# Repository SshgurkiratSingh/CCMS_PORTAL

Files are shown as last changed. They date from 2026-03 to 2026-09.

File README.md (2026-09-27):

# CCMS Portal — Centralized Command & Monitoring System

A full-stack smart streetlight fleet management system with real-time monitoring, remote control, and analytics. This monorepo contains the Next.js operator console, AWS Lambda backend, ESP32 firmware for the edge devices, and PCB designs.

## Screenshots & Assets

| Fleet Info | Node Info | Command Menu |
|:---:|:---:|:---:|
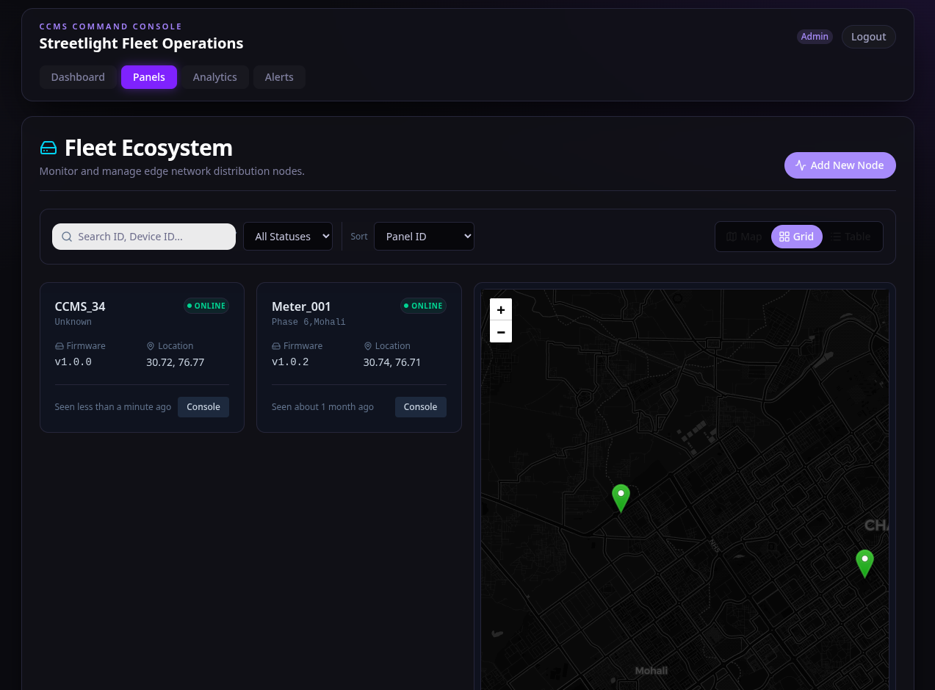
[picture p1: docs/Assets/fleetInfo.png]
Fleet
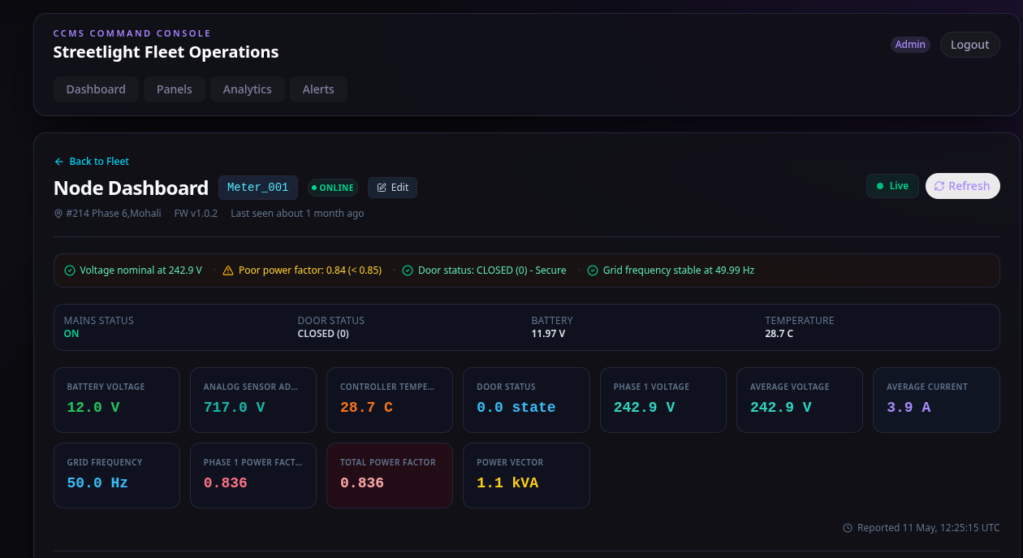
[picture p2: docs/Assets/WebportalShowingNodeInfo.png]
Node
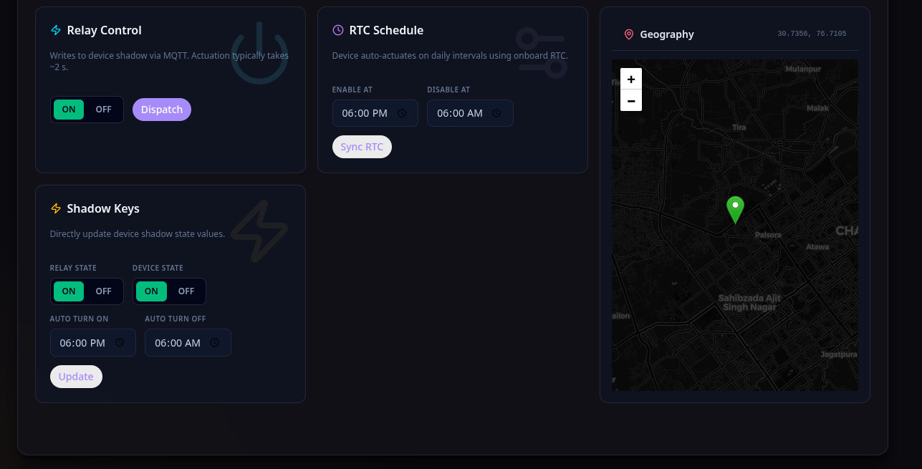
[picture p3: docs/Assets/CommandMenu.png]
Command
|  |  |  |

| Prototype | Power Supply Unit | Offsite Interface Card |
|:---:|:---:|:---:|
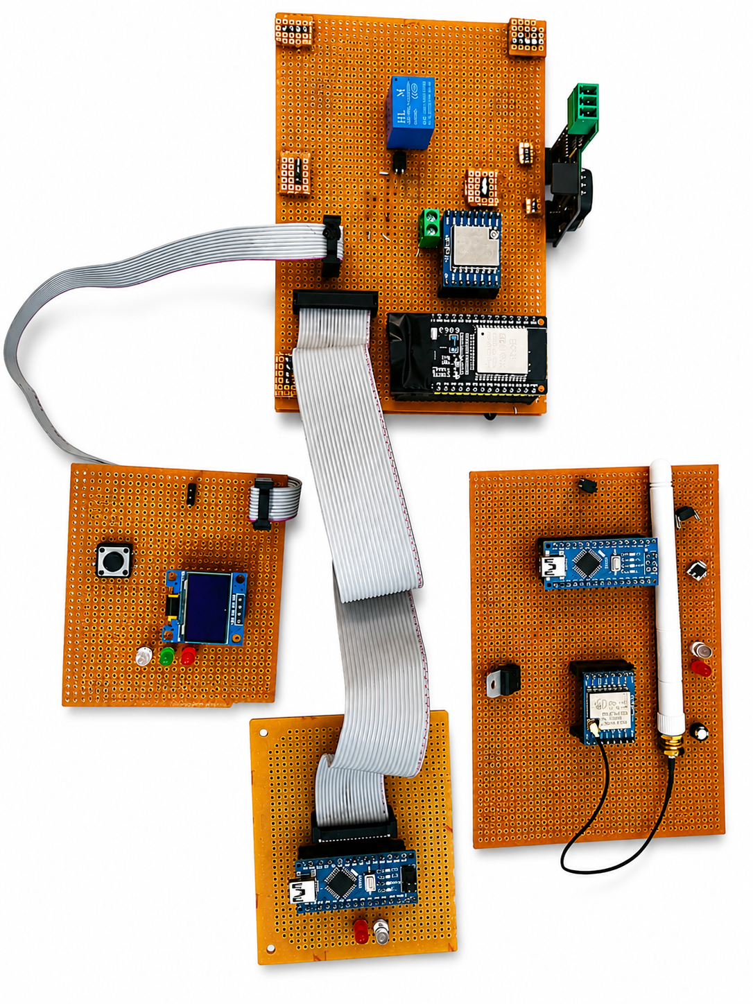
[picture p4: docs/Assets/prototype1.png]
Prototype
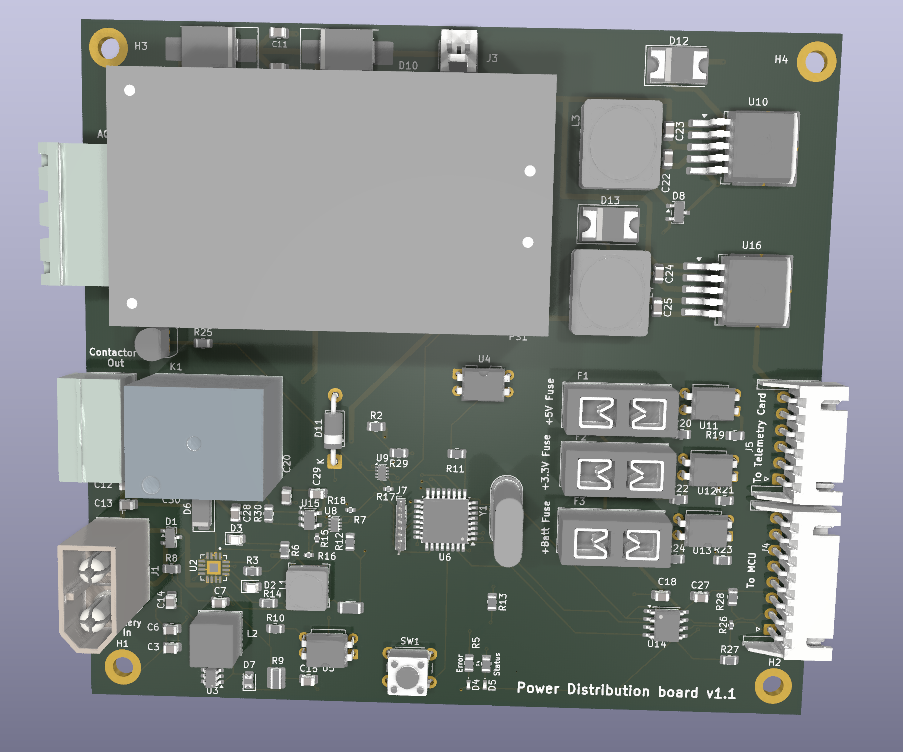
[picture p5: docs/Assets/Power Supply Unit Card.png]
PSU
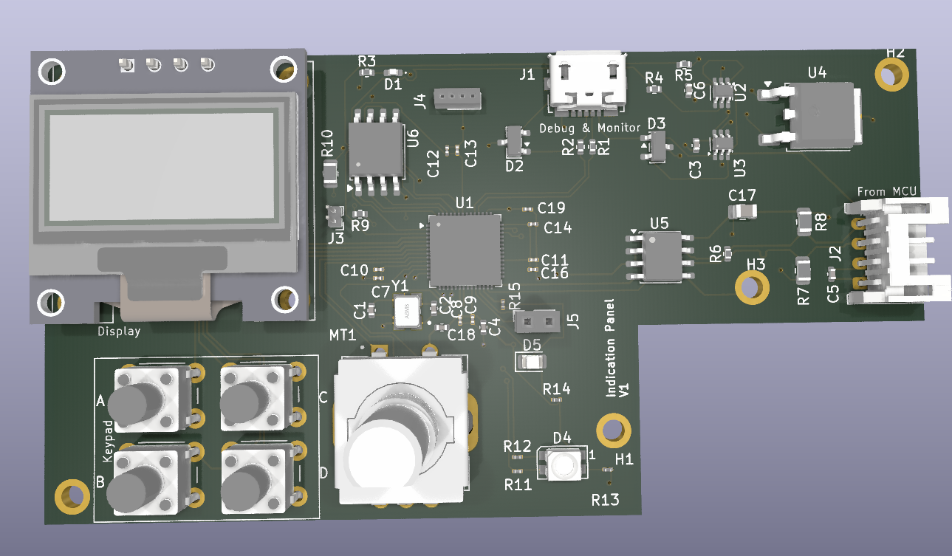
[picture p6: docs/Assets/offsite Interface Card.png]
OIC
|  |  |  |

---

## Architecture Overview

```text
┌──────────────────┐       ┌──────────────┐       ┌─────────────────┐
│ RPi Gateway + STM│──────▶│   AWS IoT    │──────▶│  SQS → Lambda   │──────▶ DynamoDB
│  (streetlights)  │  MQTT │   Core       │       │ (saveDataFromSQ)│
└──────────────────┘       └──────────────┘       └─────────────────┘
                                                          │
                                                          ▼
┌──────────────────┐       ┌──────────────┐       ┌─────────────────┐
│   Next.js App    │◀──────│   Lambda     │◀──────│  DynamoDB       │
│  (operator       │  REST │   API        │       │                 │
│   console)       │       │   Gateway    │       │                 │
└──────────────────┘       └──────────────┘       └─────────────────┘
```

### Components

| Layer | Technology | Location |
| --- | --- | --- |
| **Web Portal** | Next.js 16, React 19, Tailwind CSS v4 | [`Frontend/ccms/`](./Frontend/ccms) |
| **Backend API** | Python AWS Lambda | [`Backend/Lambda/`](./Backend/Lambda) |
| **Firmware (RPi Gateway)** | Python 3 | [`Firmware/RPi_Gateway/`](./Firmware/RPi_Gateway) |
| **Firmware (STM32 Node)** | C++ (PlatformIO), STM32 | [`Firmware/STM32_Peripheral/`](./Firmware/STM32_Peripheral) |
| **Firmware v2.0** | C++ (PlatformIO), ESP32 | [`Firmware/ESP32_wifi_CCMS_v2.0/`](./Firmware/ESP32_wifi_CCMS_v2.0) |
| **Firmware v2.0 (Pi link)** | C++ (PlatformIO), ESP32 | [`Firmware/ESP32_wifi_CCMS_v2.0_PI_link/`](./Firmware/ESP32_wifi_CCMS_v2.0_PI_link) |
| **Firmware v1.0** | C++ (PlatformIO), ESP32 | [`Firmware/ESP32_wifi_CCMS_v1.0/`](./Firmware/ESP32_wifi_CCMS_v1.0) |
| **Hardware** | PCB Designs | [`Hardware/PCB Designs/`](./Hardware/PCB%20Designs) |
| **Documentation** | MkDocs (Material theme) | [`docs/`](./docs), [`mkdocs.yml`](./mkdocs.yml) |

---

## Frontend — Operator Console (`Frontend/ccms/`)

A Next.js static export application that provides a real-time operations dashboard for managing streetlight fleets.

### Pages

| Route | Description |
| --- | --- |
| `/` | Landing page with login / dashboard links |
| `/login` | Authenticate using Dashboard Key and Admin Key |
| `/dashboard` | Fleet-wide summary (panel count, active alarms, grid metrics, energy estimate) |
| `/panels` | Browse, filter, and search all panels (map + list views) |
| `/panel?id={panelId}` | Live status, telemetry charts, command dispatch (relay, schedule, shadow keys) |
| `/manage-panel` | Register new panels with GPS coordinates |
| `/analytics` | Historical telemetry viewer with date range filtering |
| `/alerts` | Active alerts list with severity filtering and acknowledgment |

### Key Technologies

- **Framework**: Next.js 16 (`output: "export"` — fully static, no server functions)
- **UI Library**: HeroUI v3, Lucide icons
- **Charts**: Recharts (telemetry time-series)
- **Maps**: Leaflet + React-Leaflet (panel fleet locations, location picker)
- **Styling**: Tailwind CSS v4, Framer Motion (animations)
- **Auth**: API keys stored in `localStorage`, sent as `x-dashboard-key` / `x-admin-key` headers

### Environment Variables

```env
NEXT_PUBLIC_API_BASE_URL=<Lambda API Gateway endpoint>
```

Copy `Frontend/ccms/.env.example` → `Frontend/ccms/.env.local` and fill in real values.

### Run Locally

```bash
cd Frontend/ccms
npm install
npm run dev       # development server at http://localhost:3000
npm run build     # static export to Frontend/ccms/out/
```

---

## Backend — AWS Lambda (`Backend/Lambda/`)

Python-based serverless functions deployed behind API Gateway.

### Functions

| File | Purpose |
| --- | --- |
| [`lambdaAPI.py`](./Backend/Lambda/lambdaAPI.py) | REST API handler — serves dashboard snapshot, panel status, history, and commands |
| [`saveDataFromSQStoDB,py`](./Backend/Lambda/saveDataFromSQStoDB,py) | SQS-triggered function that writes incoming telemetry to DynamoDB |

### API Endpoints (via `DashboardAPIHandler`)

| Method | Query / Body | Description |
| --- | --- | --- |
| `GET` | `?enquiry=snapshot` | Returns all panels with latest data and metadata |
| `GET` | `?enquiry=history&panel_id=X&start=T&end=T` | Historical telemetry for a panel |
| `POST`  | `{ panel_id, ... }` | Register a new panel |
| `PATCH` | `{ panel_id, desired_state/schedule/shadowKeys, ... }` | Send commands to a panel |

### Test Endpoints

A Node.js test script is available at [`Backend/Lambda/TestEndpoints/getData.js`](./Backend/Lambda/TestEndpoints/getData.js) for manual API testing.

---

## Hardware — Edge Firmware

The project supports both ESP32-centric designs and a new hybrid Raspberry Pi + STM32 architecture.

| Variant | Description |
| --- | --- |
| **RPi Gateway** | Python daemon acting as an IoT gateway, handling AWS IoT MQTT and Shadow. |
| **STM32 Peripheral** | Hard-realtime STM32 node for sensors and Modbus, reports to RPi Gateway. |
| **v1.0 (ESP32)** | Base implementation with WiFi, MQTT, and energy meter reading |
| **v2.0 (ESP32)** | Enhanced version with AWS IoT Core integration, relay control, OTA-ready |
| **v2.0 PI Link (ESP32)** | Variant designed to communicate via Raspberry Pi for additional relay logic |

### Key Hardware Interfaces (RPi + STM32)

- **Raspberry Pi**: Network handling (WiFi/Ethernet), AWS IoT Core communication.
- **Serial (UART)**: Two-way communication between Pi and STM32 (Baud 115200).
- **Relay Control**: Managed by STM32 GPIO (`PA0`).
- **Modbus**: Read by STM32 via RS485 transceiver.

Build STM32 firmware with [PlatformIO](https://platformio.org/):

```bash
cd Firmware/STM32_Peripheral
pio run -t upload
```

---

## API Types

All frontend types are defined in [`Frontend/ccms/lib/api/types.ts`](./Frontend/ccms/lib/api/types.ts). Key models:

- **PanelRecord** — panel metadata, status, GPS coordinates
- **PanelLiveStatus** — real-time telemetry snapshot (voltage, current, power factor, frequency, battery, temperature, tilt)
- **TelemetryPoint** — historical data point matching live status fields
- **PanelCommandPayload** — `SET_MANUAL_STATE`, `UPDATE_RTC_SCHEDULE`, or `UPDATE_SHADOW_KEYS`
- **AlertRecord** — fault alerts with severity, status, acknowledgment tracking
- **DashboardSummary** — fleet-wide aggregate metrics

---

## Documentation

Full project documentation is built with [MkDocs](https://www.mkdocs.org/) using the Material theme.

```bash
pip install mkdocs-material
mkdocs serve       # local preview at http://127.0.0.1:8000
mkdocs gh-deploy   # publish to GitHub Pages
```

The documentation is auto-deployed via [GitHub Actions](https://github.com/settings/actions) on pushes to `main` that touch `docs/` or `mkdocs.yml`.

### Included Docs

- [Frontend & Lambda Report](./docs/frontend-lambda-project-report.md)
- [Web Portal Guide](./docs/web-portal.md)
- [Hardware (ESP32)](./docs/hardware.md)
- [Lambda Backend](./docs/lambda.md)

---

## CI / CD

| Workflow | Trigger | Action |
| --- | --- | --- |
| [`gh-pages.yml`](.github/workflows/gh-pages.yml) | Push to `main` (docs changes) | Builds and deploys MkDocs to GitHub Pages |

---

## Project Structure

```text
CCMS_PORTAL/
├── Frontend/
│   └── ccms/                          ← Next.js operator console
├── Backend/
│   └── Lambda/                        ← AWS Lambda backend
├── Firmware/
│   ├── RPi_Gateway/                   ← Raspberry Pi Python daemon
│   ├── STM32_Peripheral/              ← STM32 hardware controller
│   ├── ESP32_wifi_CCMS_v1.0/          ← Firmware v1.0
│   ├── ESP32_wifi_CCMS_v2.0/          ← Firmware v2.0
│   └── ESP32_wifi_CCMS_v2.0_PI_link/  ← Firmware v2.0 (Pi link variant)
├── Hardware/
│   └── PCB Designs/                   ← Hardware designs
├── docs/                          ← MkDocs documentation source
├── mkdocs.yml                     ← Documentation site configuration
└── .github/workflows/             ← CI/CD pipelines
```

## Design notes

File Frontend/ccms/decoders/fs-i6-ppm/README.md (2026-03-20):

# FS i6 PPM Decoder for PulseView/Sigrok

Decoder for FlySky i6 PPM (Pulse Position Modulation) RC control signals.

## Installation

### Option 1: User installation (recommended)

```bash
# Copy decoder to user directory
cp -r decoders/fs-i6-ppm ~/.local/share/sigrok/decoders/

# Set environment variable (add to ~/.bashrc for persistence)
export SIGROKDECODE_DIR=~/.local/share/sigrok/decoders

# Start PulseView
pulseview
```

### Option 2: System-wide installation (requires root)

```bash
sudo cp -r decoders/fs-i6-ppm /usr/share/libsigrokdecode/decoders/
```

## Usage in PulseView

1. Capture PPM signal with a logic analyzer
2. Add decoder → Select "FS i6 PPM"
3. Assign the PPM signal channel
4. Adjust options if needed

## Protocol Details

### PPM Signal Characteristics

- **Sync Pulse**: 350-500µs (marks frame start)
- **Channel Pulses**: 800-2200µs (1000-2000µs typical range)
- **Channel Spacing**: ~400µs between pulse starts
- **Frame Period**: ~22.5ms
- **Channels**: 6-10 (FS i6 typically uses 6-10 channels)

### Pulse Width Mapping

| Pulse Width | Throttle/Control |
|---|---|
| 1000µs | Minimum (0%) |
| 1500µs | Neutral (50%) |
| 2000µs | Maximum (100%) |

## Decoder Options

| Option | Default | Description |
|---|---|---|
| `sync_min` | 350 | Minimum sync pulse width (µs) |
| `sync_max` | 500 | Maximum sync pulse width (µs) |
| `pulse_min` | 800 | Minimum channel pulse width (µs) |
| `pulse_max` | 2200 | Maximum channel pulse width (µs) |
| `channel_spacing` | 400 | Expected channel spacing (µs) |
| `max_channels` | 10 | Maximum channels to decode |
| `frame_timeout` | 25 | Frame timeout threshold (ms) |

## Wiring

Connect your PPM signal from the RC receiver to the logic analyzer:

```
FS i6 Receiver → Logic Analyzer
    PPM OUT     →    Channel 0
    GND         →    GND
```

## Annotations

- **Sync**: Frame synchronization pulse
- **Channel**: Individual channel pulses
- **Channel Value**: Pulse width in microseconds
- **Warning**: Invalid pulses or protocol errors
- **Frame**: Frame boundaries

## License

GPL-3.0 or later

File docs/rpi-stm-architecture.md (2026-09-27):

# Raspberry Pi & STM Architecture

## Overview
As the CCMS deployment scales, the edge computing architecture is migrating from a standalone ESP32 system to a hybrid Raspberry Pi Gateway + STM32 Peripheral model.

This model delegates heavy network operations (AWS IoT MQTT, TLS decryption, NTP, scheduling) to the Raspberry Pi running Linux, while preserving real-time hardware determinism (ADC sampling, Modbus polling, relay control) on an STM32 peripheral node.

## Hardware Connections

1. **Serial (UART)**
   - Pi `TX` (GPIO 14) -> STM32 `RX` (PA10)
   - Pi `RX` (GPIO 15) -> STM32 `TX` (PA9)
   - Set baudrate to `115200`
2. **Relay Control**
   - STM32 `PA0` controls the solid-state or mechanical relay for the streetlight.
3. **Sensors**
   - **Battery ADC**: STM32 `PA1`
   - **Mains AC ADC**: STM32 `PA2`
   - **Tilt Switch**: STM32 `PA3`
4. **Power Meter (Modbus RTU)**
   - STM32 Serial2 -> RS485 Transceiver -> Schneeler Power Meter

## Software Components

### 1. RPi Gateway (`Firmware/RPi_Gateway/`)
A Python-based daemon (`main.py`) running on the Raspberry Pi.
- Uses `AWSIoTPythonSDK` to securely communicate with AWS IoT Core.
- Uses `pyserial` to communicate with the STM32.
- Handles AWS Device Shadow deltas (e.g. changing the relay state).

**Setup:**
```bash
sudo apt-get update
sudo apt-get install python3-pip
pip3 install -r Firmware/RPi_Gateway/requirements.txt
```

### 2. STM32 Peripheral (`Firmware/STM32_Peripheral/`)
Developed using PlatformIO with the Arduino framework for STM32.
- Polled every 5 seconds by internal timer to send a JSON telemetry string over UART.
- Listens for JSON commands from the Pi to toggle the relay.

**Build and Upload:**
```bash
cd Firmware/STM32_Peripheral
pio run -t upload
```

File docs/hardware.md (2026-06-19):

# Hardware (ESP32)

Three firmware variants for ESP32 microcontrollers that communicate telemetry and receive commands over WiFi/MQTT through AWS IoT Core.

Modular Centralised Management System

---

## Firmware Variants

| Variant | Path | Description |
| --- | --- | --- |
| **v1.0** | `ESP32_wifi_CCMS_v1.0/` | Base implementation with WiFi, MQTT, and basic energy meter reading |
| **v2.0** | `ESP32_wifi_CCMS_v2.0/` | Enhanced version with AWS IoT Core integration, relay control, UART comms bridge, OLED display, and NTP-synchronized RTC |
| **v2.0 PI Link** | `ESP32_wifi_CCMS_v2.0_PI_link/` | Variant designed to communicate via Raspberry Pi for additional relay logic and protocol bridging |

## Development Environment

All variants use **PlatformIO** with the Espressif 32 platform.

```bash
pip install platformio
cd ESP32_wifi_CCMS_v2.0
pio run -t upload     # build and flash
pio device monitor    # serial console at 115200 baud
```

### Key Dependencies (v2.0)

| Library | Version | Purpose |
| --- | --- | --- |
| `ArduinoJson` | ^7.2.2  | JSON serialization for MQTT payloads |
| `PubSubClient` | ^2.8 | MQTT client for AWS IoT Core |
| `ModbusMaster` | ^2.0.1  | Modbus RTU communication via RS-485  |
| `RTClib` | ^2.1.3  | DS3231 RTC driver |
| `Adafruit SSD1306` | ^2.5.9  | OLED display driver |
| `Adafruit GFX Library` | - | Graphics primitives for display |

---

## Hardware Architecture (v2.0)

### Pin Mapping

| Function | Pin | Interface | Details |
| --- | --- | --- | --- |
| **Mains ADC** | 35  | Analog | AC mains voltage measurement via voltage divider |
| **Battery ADC** | 34  | Analog | Backup battery voltage monitoring |
| **Tilt Switch** | 15  | Digital (input)  | Mechanical tilt/tamper detection (internal pull-up) |
| **DHT11 Temp** | 4 | Digital (1-wire) | Chassis temperature sensor |
| **Relay Control** | 14  | Digital (output) | Transistor-driven AC contactor actuation |
| **Modbus RX** | 16  | UART2 RX | RS-485 receive (MAX485) |
| **Modbus TX** | 17  | UART2 TX | RS-485 transmit (MAX485) |
| **Comms Bridge RX** | 13  | UART1 RX | External radio module receive (LoRa, nRF, etc.) |
| **Comms Bridge TX** | 12  | UART1 TX | External radio module transmit (payload mirror) |
| **I2C SDA** | 21  | I2C | Shared bus: DS3231 RTC + SSD1306 OLED |
| **I2C SCL** | 22  | I2C | Shared bus: DS3231 RTC + SSD1306 OLED |
| **OLED Button** | 32  | Digital (input)  | Debounced tactile switch for screen cycling |
| **LED 1 (Mains)** | 25  | Digital (output) | Green — solid when mains voltage > threshold |
| **LED 2 (Cloud)** | 26  | Digital (output) | Blue — solid when WiFi + MQTT connected |
| **LED 3 (TX)** | 27  | Digital (output) | Flashes on each MQTT publish (25s interval) |

### Peripheral Configuration

- **Modbus (UART2):** 9600 baud, 8E1 (8 data bits, Even parity, 1 stop bit)
- **Comms Bridge (UART1):** 115200 baud, 8N1
- **I2C:** DS3231 RTC (addr `0x68`), SSD1306 OLED (addr `0x3C`)
- **OLED Screens:** 3 modes — OS stats, environmental stats, load parameters

---

## Communication Architecture

### Primary: AWS IoT Core (MQTT over mTLS)

- **Telemetry topic:** `meter/telemetry/Meter_001`
- **Shadow topic:** `$aws/things/Meter_001/shadow/update/delta`
- **Publish interval:** Every 25 seconds
- **Security:** Mutual TLS authentication with hardcoded device certificate

### Secondary: UART Comms Bridge

Every MQTT payload is mirrored over UART1 (TX pin 12) at 115200 baud for external radio modules (LoRa, nRF24 Mesh, Wi-Fi HaLow). This decouples RF protocol complexity from the ESP32 firmware.

### Telemetry Payload

The JSON payload published every 25 seconds includes:

- Epoch timestamp (from NTP-synced DS3231 RTC)
- Modbus register values (voltage, current, power factor, frequency, power)
- Battery voltage (ADC reading)
- Mains voltage raw (ADC reading)
- Tilt switch state
- DHT11 temperature reading

---

## Software Subsystems

### NTP + DS3231 Time Sync

1. On WiFi connect, fetches epoch from `pool.ntp.org` / `time.nist.gov`
2. Adjusts to IST (+5:30) and writes to DS3231 RTC via `rtc.adjust()`
3. If WiFi fails, falls back to RTC crystal for timestamping

### AWS Device Shadow

Subscribes to `$aws/things/Meter_001/shadow/update/delta` for:

| Shadow Key | Effect |
| --- | --- |
| `relay_state` | Immediately sets relay pin HIGH/LOW |
| `timeToAutoTurnOn`  | Sets automatic turn-on time (e.g., 18:00)  |
| `timeToAutoTurnOff` | Sets automatic turn-off time (e.g., 06:00) |
| `device_state` | Sets operational mode (Active/Maintenance) |

### Modbus Polling Loop

- Reads predefined holding registers (3003, 3009, etc.) via `ModbusMaster.h`
- 120ms inline delay between reads for RS-485 bus timing
- Byte-swaps if required, decodes to float, validates against NaN/Infinity
- Stores results in `mqttValues[]` global buffer for next publish

### Main Loop Structure

```
loop():
  1. Verify WiFi — auto-reconnect + re-fire NTP if needed
  2. mqttClient.loop() — sustain TLS keep-alive
  3. Read ADC: batteryVoltage, mainsRaw, tiltSwitchState
  4. Debounce button — rotate OLED screen (modulo 3)
  5. Render OLED display with current globals
  6. Modbus register reads
  7. If millis() - lastMqttPublish >= 25000:
     - Serialize JSON
     - Publish to MQTT
     - Mirror to UART bridge
     - Toggle TX LED
```

---

## v1.0 vs v2.0 vs v2.0 PI Link

| Feature | v1.0 | v2.0 | v2.0 PI Link |
| --- | ---- | ---- | --- |
| WiFi + MQTT | ✅ | ✅ | ✅ |
| AWS IoT Core mTLS | ❌ | ✅ | ✅ |
| Modbus Energy Meter | ✅ | ✅ | ✅ |
| DS3231 RTC + NTP | ❌ | ✅ | ✅ |
| OLED Display | ❌ | ✅ | ✅ |
| UART Comms Bridge | ❌ | ✅ | ✅ |
| AWS Device Shadow | ❌ | ✅ | ✅ |
| Relay Control | ❌ | ✅ | Via Pi |
| PI Communication | ❌ | ❌ | ✅ |

## Building and Flashing

Each firmware variant has the same PlatformIO structure:

```
ESP32_wifi_CCMS_v2.0/
├── platformio.ini          ← Build configuration
├── include/
│   ├── config.h            ← WiFi/MQTT credentials and pin definitions
│   ├── mqtt_handler.h      ← MQTT client declarations
│   ├── wifi_handler.h      ← WiFi manager declarations
│   ├── meter_handler.h     ← Modbus handler declarations
│   └── aws_certs.h         ← AWS IoT Core certificates (v2.0+)
├── src/
│   ├── main.cpp            ← Entry point and main loop
│   ├── config.cpp          ← Configuration loading
│   ├── mqtt_handler.cpp    ← MQTT publish/subscribe logic
│   ├── wifi_handler.cpp    ← WiFi connection management
│   └── meter_handler.cpp   ← Modbus polling implementation
├── test/                   ← Unit tests
├── FLOW_DIAGRAMS.md        ← System flow documentation
├── PROJECT_REPORT.md       ← Comprehensive project report
└── publish_test.py         ← MQTT publish test script
```

### Configuration

Edit `include/config.h`:

```cpp
// WiFi
#define WIFI_SSID "your_ssid"
#define WIFI_PASSWORD "your_password"

// AWS IoT
#define AWS_IOT_ENDPOINT "xxxxxxxxxxxxxx-ats.iot.ap-south-1.amazonaws.com"

// MQTT Topics
#define MQTT_TELEMETRY_TOPIC "meter/telemetry/Meter_001"
#define MQTT_SHADOW_TOPIC "$aws/things/Meter_001/shadow/update/delta"

// Modbus
#define MODBUS_SLAVE_ID 1
#define MODBUS_BAUD 9600
```

For v2.0, also configure `include/aws_certs.h` with the device certificate, private key, and Amazon Root CA.

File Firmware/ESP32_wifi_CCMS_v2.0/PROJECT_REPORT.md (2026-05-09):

# Centralized Control and Monitoring System (CCMS)

## ESP32 V2.0 Firmware and System Architecture Comprehensive Report

---

## 1. Executive Summary

The Centralized Control and Monitoring System (CCMS) V2.0 represents a sophisticated, scalable IoT edge node designed specifically for rigorous industrial and commercial energy grid monitoring. Powered by the dual-core ESP32 microcontroller, the V2.0 firmware establishes a highly resilient architecture capable of processing complex electrical parameters, sensing structural and environmental environments, maintaining accurate asynchronous schedules, and interacting with AWS IoT Core.

Recognizing the limitations of relying purely on standard 2.4 GHz Wi-Fi for industrial deployments, the hallmark of V2.0 is the integration of a **decoupled UART expansion bridge**. This architecture enables external long-range or alternative-network transceiver cards (such as LoRa, nRF Mesh, or 802.11ah Wi-Fi HaLow) to natively intercept telemetry streams, ensuring data ingress into the cloud even in harsh RF Topographies.

---

## 2. Hardware Architecture & Peripheral Mapping

The ESP32 coordinates a dense array of peripherals, balancing dual UART buses, an I2C shared bus, analog digital converters (ADCs), and digital GPIOs without thread blockage.

### 2.1 Core Electrical & Environmental Sensors

- **Mains Voltage Sensing (Pin 35 - `MAINS_ADC_PIN`):** Utilizes the ESP32's 12-bit ADC. Tracks the presence and voltage levels of the primary AC supply via a scaled step-down conversion network.
- **Backup Battery Health (Pin 34 - `BAT_ADC_PIN`):** Constant analog sampling of the system's DC backup power supply, protecting against sudden data loss.
- **Tamper / Tilt Detection (Pin 15 - `TILT_SW_PIN`):** A mechanical tilt switch connected via an internal pull-up resistor. Actuates if a deployment cabinet is knocked over, vandalized, or physically compromised.
- **Temperature (Pin 4 - `DHT_PIN`):** A DHT11 digital interface currently recording localized chassis temperature, structurally mapped for a future industrial RTD (Resistance Temperature Detector) upgrade.
- **Actuation Relay (Pin 14 - `RELAY_PIN`):** Transistor-driven GPIO enabling the CCMS node to actively toggle external AC contactors (for lighting or breaker loads) either autonomously based on scheduled timing, or manually via remote AWS Shadow triggers.

### 2.2 Serial Topologies

- **Modbus Meter Link (UART 2):**
  - **Pins:** RX: 16, TX: 17
  - **Driver:** MAX485 / RS-485 level shifter.
  - **Specification:** 9600 baud, 8E1 (8 data bits, Even parity, 1 stop bit). Exclusively acts to poll standard Holding Registers from the external multi-function energy meter.
- **Remote Comms Bridge (UART 1):**
  - **Pins:** RX: 13, TX: 12
  - **Specification:** 115200 baud, 8N1. The master outgoing payload mirror for auxiliary radio cards.
- **Display & Timing (I2C Bus):**
  - **Pins:** SDA: 21, SCL: 22
  - **Devices:** Shared multi-master loop tracking a DS3231 Real-Time Clock and SSD1306 128x64 OLED Display. Address collision is physically avoided (RTC usually `0x68`, Display `0x3C`).

### 2.3 Human-Machine Interface (HMI)

- **Display:** Adafruit SSD1306 OLED screen rendering segmented GUI blocks for direct field-technician interaction.
- **Navigation Button (Pin 32):** Hardware-debounced tactile button used by field agents to dynamically cycle the OLED screen modes without interrupting the device's polling logic.
- **Triple-Status Diagnostics (LEDs):**
  - **LED 1 (Pin 25):** Solid green when `MAINS_ADC_PIN` exceeds a raw value of 500 (indicating healthy incoming power).
  - **LED 2 (Pin 26):** Solid blue whenever the system possesses dual-authentication (Wi-Fi associated + AWS MQTT connected).
  - **LED 3 (Pin 27):** Intermits/flashes every 25 seconds concurrent with a successful MQTT JSON payload dispatch, offering an absolute visual confirmation of packet flow.

---

## 3. Communication Pathways & Cloud Synergy

### 3.1 Primary Wi-Fi & AWS IoT Encrypted Stream

The system connects to local 802.11b/g/n networks, escalating standard TCP traffic to a fully secured mutual-TLS (mTLS) session using hard-coded private keys and certificates (`credentials/` payload) targeting an AWS IoT Core endpoint ().

- **Telemetry Stream:** Routine JSON structures (up to 1024 bytes) push natively to `meter/telemetry/Meter_001`. The backend AWS core handles rule processing to shift this into databases.
- **JSON Architecture:** The serialized payload integrates epoch timestamps, 32-bit Modbus floating point values, Battery/Mains analog interpretations, physical tilt statuses, and the DHT reading.

### 3.2 Extensible Comms Bridge (UART 1 - The Secondary RF Link)

To secure the physical infrastructure against Wi-Fi failures, range limits, or extreme multi-path interference common in substations, the CCMS node utilizes `Serial1` as a mirrored data bridge.

- **How it Works:** Any time the `publishMqttData()` function executes serialization for AWS, that identical `payload.c_str()` is shunted downstream across Pin 12 (TX) at 115200 baud.
- **External Integration (nRF, LoRa, Wi-Fi HaLow):** An attached third-party communication expansion board (e.g., custom LoRaWAN module, nRF24 Mesh relay) simply UART-Rx's the framed JSON data and repackets it via its specific PHY layer. This ensures that the CCMS ESP32 doesn't need to bloat its firmware with specific RF protocol stacks; it merely acts as a standardized data fountain.

---

## 4. Software Subsystems and Execution Threads

### 4.1 Chronological Synchronization (NTP + DS3231)

The CCMS guarantees sub-second timestamping accuracy even amidst rolling blackouts. Upon connecting to Wi-Fi, the core invokes an NTP packet request to `pool.ntp.org` (and `time.nist.gov`).
Once a valid stratum epoch is captured (and scaled by +5.5 hours for IST), it is permanently written into the DS3231 hardware register via `rtc.adjust()`. If Wi-Fi fails entirely, internet-independent timestamping is continuously derived from the local RTC crystal.

### 4.2 State Twin (AWS Device Shadows)

The device subscribes structurally to the MQTT Topic: `$aws/things/Meter_001/shadow/update/delta`.
When a master system administrator issues a change command on the AWS console, the local node receives a parsed `JsonObject "state"`. Known vector overrides include:

- `relay_state`: Directly forces the Relay Pin 14 High/Low immediately.
- `timeToAutoTurnOn` / `timeToAutoTurnOff`: Mutates localized global variables detailing automated schedules (e.g., 18:00 start, 06:00 kill) ensuring physical logic operates independent of live server pinging.
- `device_state`: An administrative string indicating the logical mode of operation (Active vs Maintenance mode).

### 4.3 Modbus Polling (IEC 61131 Compliant)

Leveraging `ModbusMaster.h`, CCMS node systematically loops over `numMqttRegs` predefined IEEE-754 endpoints (e.g., 3003, 3009). The registers are physically demanded via `node.readHoldingRegisters()`.
Each read applies an inline 120ms blocking delay to respect standard RS-485 bus timing boundaries. Values are returned as dual 16-bit blocks, natively joined, byte-swapped if structurally required via `useByteSwap` logic, decoded to C++ floats, validated recursively against `NaN` and `Infinity` errors, and lastly pooled into the `mqttValues[]` global array buffer.

### 4.4 The Asynchronous Main Loop

The `loop()` function in `main.cpp` runs at a virtually unbounded frequency. Its structure:

1. Verify Wi-Fi topology (Auto-reconnect + Re-fire NTP).
2. Ping `mqttClient.loop()` to sustain TLS keep-alive.
3. Execute local ADC mapping (`batteryVoltage`, `mainsRaw`, `tiltSwitchState`).
4. Capture physical debounces on `BUTTON_PIN`. Rotate the `currentScreen` modal flag strictly modulo 3.
5. Render the local OLED display using current globals (0: OS stats, 1: Envo stats, 2: Load parameters).
6. Fire Modbus array reads.
7. Check `millis() - lastMqttPublish >= 25000`. If triggered, serialize JSON memory pool, flush to MQTT stream, flush to UART Bridge, and flip LED 3.

---

## 5. Development Dependencies & Compilations

The system is constructed under Espressif 32 (via PlatformIO CLI).
Vital `lib_deps` components driving execution logic:

- **`bblanchon/ArduinoJson@^7.2.2`**: Memory-efficient serialization engine mapping the vast array outputs into pure UTF-8 JSON templates.
- **`knolleary/PubSubClient@^2.8`**: Thread-safe MQTT client wrapper framing standard QoS messages to AWS.
- **`4-20ma/ModbusMaster@^2.0.1`**: Highly reliable protocol driver decoding complex sequential framing via UART2.
- **`adafruit/RTClib@^2.1.3`**: Simplifies standard I2C register mathematics shifting UNIX timescales natively into the DS3231 module.
- **`adafruit/Adafruit SSD1306@^2.5.9` + `GFX Library`**: Memory-mapped OLED graphics handler preventing pixel burn and ghosting.

## 6. Forward Progression

CCMS V2.0 establishes an impenetrable architecture baseline for true industrial monitoring. Integrating the offline RTC, real-time AWS shadow handling, comprehensive multi-tier environmental logging, and the heavily modular UART1 communications bridge ensures the system is practically future-proof. Whether scaled into Wi-Fi heavy infrastructure or relegated into dense concrete zones requesting Sub-GHz routing, the core intelligence remains static, pristine, and wholly isolated.

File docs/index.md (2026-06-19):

# CCMS Portal Documentation

Welcome to the **Centralized Command & Monitoring System** (CCMS) documentation. This system provides end-to-end management of smart streetlight fleets — from ESP32 edge firmware through AWS cloud infrastructure to the web-based operator console.

---

## Screenshots

Fleet Overview

Panel Command Center

Modular Centralised Management System

---

## Architecture

```
┌──────────────────┐    MQTT    ┌──────────────┐    SQS     ┌─────────────────┐
│   ESP32 Nodes    │───────────▶│   AWS IoT     │──────────▶│  Ingestion      │──────▶ DynamoDB
│  (streetlights)  │            │   Core        │            │  Lambda         │       (MeterTelemetry)
└──────────────────┘            └──────────────┘            └─────────────────┘
                                                                      │
                                                                      │ Read
                                                                      ▼
┌──────────────────┐    REST    ┌──────────────┐     Query    ┌─────────────────┐
│   Next.js App    │◀──────────│  API Gateway  │◀────────────│  DynamoDB       │
│  (operator       │            │  → Lambda    │              │  (PanelMetadata │
│   console)       │            │  (lambdaAPI)  │              │   + Telemetry)  │
└──────────────────┘            └──────────────┘              └─────────────────┘
```

## System Components

| Component | Technology | Description |
|---|---|---|
| **Web Portal** | Next.js 16, React 19, Tailwind CSS v4 | Operator console for fleet monitoring, command dispatch, analytics, and alerts |
| **API Lambda** | Python 3.x, AWS Lambda | REST API handling snapshot, history, provisioning, and commands via SSM-authenticated endpoints |
| **Ingestion Lambda** | Python 3.x, AWS Lambda | SQS-triggered function that writes telemetry payloads into DynamoDB |
| **ESP32 Firmware** | C++ (PlatformIO) | Edge device firmware for WiFi, MQTT/IoT Core, Modbus energy metering, and relay control |
| **Documentation** | MkDocs (Material theme) | This documentation site, auto-deployed to GitHub Pages |

## Data Flow

1. **ESP32 nodes** publish telemetry (voltage, current, power factor, battery, temperature, etc.) to AWS IoT Core via MQTT.
2. **IoT rules** route incoming messages to an **SQS queue**.
3. **Ingestion Lambda** (`saveDataFromSQStoDB`) reads from SQS and writes records to the `MeterTelemetry` DynamoDB table.
4. **API Lambda** (`lambdaAPI.py`) serves data to the frontend:
   - `?enquiry=snapshot` — scans `PanelMetadata` and attaches latest 5 telemetry records per panel
   - `?enquiry=history` — queries `MeterTelemetry` by panel ID and time range
   - `POST`/`PUT` — provisions/updates panel metadata
   - `PATCH` — dispatches relay commands, schedule updates, or shadow key changes (published to IoT Device Shadow)
   - `DELETE` — decommissions a panel
5. **Web portal** consumes the API using key-based auth headers and renders dashboards, maps, charts, and command interfaces.

## Quick Links

- [Web Portal Guide](web-portal.md) — Routes, components, auth, and deployment
- [Lambda Backend](lambda.md) — API endpoints, auth model, DynamoDB schema
- [Hardware (ESP32)](hardware.md) — Firmware variants, build instructions, interfaces
- [Frontend & Lambda Report](frontend-lambda-project-report.md) — Comprehensive architecture and implementation analysis

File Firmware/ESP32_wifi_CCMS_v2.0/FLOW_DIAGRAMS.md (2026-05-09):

# CCMS V2.0 Firmware - Mermaid Flow Diagrams

This file contains Mermaid.js diagrams illustrating the hardware architecture, main software execution loop, and the AWS Device Shadow data flow of the CCMS ESP32 V2.0 System.

You can view these diagrams natively in VS Code by installing a Markdown preview extension that supports Mermaid (like "Markdown Preview Mermaid Support"), or by pasting the code blocks into the [Mermaid Live Editor](https://mermaid.live).

## 1. System Hardware Architecture

This diagram outlines the physical hardware topology, illustrating what is connected to the ESP32 and via which interfaces.

```mermaid
graph TD
    %% Core Node
    ESP[ESP32 Master Core]

    %% Cloud & External Comm layer
    AWS((AWS IoT Core))
    COMM_CARD[External Comms Card<br>LoRa / nRF / HaLow]

    %% I2C Peripherals
    RTC[DS3231 RTC]
    OLED[SSD1306 Display]

    %% Serial Peripherals
    METER[Multi-function Modbus Meter]

    %% Sensors & IO
    RELAY[Actuation Relay]
    BTN((Push Button))
    DHT[DHT11 Temp Sensor]
    TILT[Tilt Switch]
    BAT[Battery ADC]
    MAINS[Mains ADC]
    LEDS[LED Diagnostics]

    %% Connections
    ESP <-->|Wi-Fi / mTLS| AWS
    ESP -->|UART1 Bridge - TX 12, RX 13| COMM_CARD
    ESP <-->|UART2 RS-485 - TX 17, RX 16| METER

    ESP <-->|I2C - SDA 21, SCL 22| RTC
    ESP <-->|I2C - SDA 21, SCL 22| OLED

    ESP -->|GPIO 14| RELAY
    ESP -->|GPIO 25, 26, 27| LEDS
    BTN -->|GPIO 32 with Debounce| ESP
    DHT -->|GPIO 4| ESP
    TILT -->|GPIO 15| ESP
    BAT -->|Analog GPIO 34| ESP
    MAINS -->|Analog GPIO 35| ESP

    classDef core fill:#f9f,stroke:#333,stroke-width:2px;
    classDef cloud fill:#ff9,stroke:#333,stroke-width:2px;
    class ESP core;
    class AWS cloud;
```

---

## 2. Main Software Execution Loop

This flowchart visualizes the non-blocking execution thread running inside the `loop()` function of `main.cpp`.

```mermaid
flowchart TD
    Start((Loop Start)) --> WiFiCheck{Is Wi-Fi<br>Connected?}

    WiFiCheck -- No --> Reconnect[Reconnect Wi-Fi<br>& Sync NTP Time] --> MQTTCheck
    WiFiCheck -- Yes --> MQTTCheck[Handle MQTT<br>Connection & loop]

    MQTTCheck --> ADCPoll[Poll ADCs & Sensors:<br>Battery, Mains, Tilt, Temp]

    ADCPoll --> ButtonCheck{Button<br>Pressed?}
    ButtonCheck -- Yes --> Cycle[Cycle currentScreen ID] --> RenderOLED
    ButtonCheck -- No --> RenderOLED[Render OLED Display<br>Based on currentScreen]

    RenderOLED --> LEDCheck[Update Status LEDs<br>Mains, Net Link]
    LEDCheck --> ModbusPoll[Read Modbus<br>Holding Registers]

    ModbusPoll --> TimeCheck{Millis - LastPub<br>>= 25000ms?}

    TimeCheck -- Yes --> Serialize[Serialize Telemetry JSON]
    Serialize --> PubAWS[Publish to AWS IoT Core]
    PubAWS --> PubUART[Print JSON to UART1 Bridge]
    PubUART --> ToggleLED[Toggle LED3 Heartbeat]
    ToggleLED --> End((Loop End))

    TimeCheck -- No --> End((Loop End))
    End -.-> Start
```

---

## 3. Remote Control & AWS Shadow Delta Flow

This sequence diagram shows how remote control commands flow from the Cloud (AWS) down down to the end-node components.

```mermaid
sequenceDiagram
    participant Admin as User / Server
    participant AWS as AWS IoT Core
    participant ESP as ESP32 (mqttCallback)
    participant HW as Hardware (Relay/Variables)
    participant Bridge as UART1 Bridge

    Admin->>AWS: Request State Change (e.g. Relay ON)
    AWS-->>ESP: Push JSON to shadow/update/delta
    ESP->>ESP: parse JSON payload

    alt JSON Contains "relay_state"
        ESP->>HW: digitalWrite(RELAY_PIN, state)
    end

    alt JSON Contains Timers/Schedules
        ESP->>HW: Update global schedule strings
    end

    alt JSON Contains "device_state"
        ESP->>HW: Update currentDeviceState string
    end

    ESP->>ESP: Build Shadow Reported JSON
    ESP->>AWS: Publish Reported JSON to shadow/update
    Note over ESP, AWS: Syncs the Cloud's "Reported" state <br> with reality.

    ESP->>Bridge: Print Reported JSON to Serial1
    Note over Bridge: External comms cards (LoRa etc.)<br>can eavesdrop on the shadow sync.
```

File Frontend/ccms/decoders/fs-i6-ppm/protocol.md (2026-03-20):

##
## This file is part of the sigrok project.
##
## Copyright (C) 2024 Gurkirat Singh
##
## This program is free software: you can redistribute it and/or modify
## it under the terms of the GNU General Public License as published by
## the Free Software Foundation, either version 3 of the License, or
## (at your option) any later version.
##
## This program is distributed in the hope that it will be useful,
## but WITHOUT ANY WARRANTY; without even the implied warranty of
## MERCHANTABILITY or FITNESS FOR A PARTICULAR PURPOSE.  See the
## GNU General Public License for more details.
##
## You should have received a copy of the GNU General Public License
## along with this program.  If not, see <http://www.gnu.org/licenses/>.
##

# FS i6 PPM (Pulse Position Modulation) Decoder
# 
# Protocol description:
# - PPM is used in RC systems to transmit channel data
# - Frame starts with a long sync pulse (~400µs low)
# - Each channel is represented by a pulse width (1000-2000µs typical)
# - Channels are multiplexed in time with ~400µs spacing
# - FS i6 typically has 6-10 channels
# - Total frame period: ~22.5ms

id: fs-i6-ppm
name: FS i6 PPM
longname: FlySky i6 Pulse Position Modulation
desc: Decoder for FlySky i6 PPM RC control signals
inputformats: logic
outputformats: proto
tagline: FlySky i6 PPM decoder
tags: rc, ppm, radio, flysky

## Channel definitions
channels:
  - name: PPM
    type: logic
    desc: PPM signal line

## Decoder options
options:
  - id: sync_min
    desc: Minimum sync pulse width (µs)
    type: int
    default: 350
  - id: sync_max
    desc: Maximum sync pulse width (µs)
    type: int
    default: 500
  - id: pulse_min
    desc: Minimum channel pulse width (µs)
    type: int
    default: 800
  - id: pulse_max
    desc: Maximum channel pulse width (µs)
    type: int
    default: 2200
  - id: channel_spacing
    desc: Expected channel spacing (µs)
    type: int
    default: 400
  - id: max_channels
    desc: Maximum number of channels to decode
    type: int
    default: 10
  - id: frame_timeout
    desc: Frame timeout threshold (ms)
    type: int
    default: 25

## Annotation definitions
annotations:
  - tag: sync
    desc: Frame sync pulse
  - tag: channel
    desc: Channel pulse with value
  - tag: channel-value
    desc: Channel number and pulse width
  - tag: warning
    desc: Protocol warnings and errors
  - tag: frame
    desc: Frame markers

annotationrows:
  - id: events
    desc: Events
    annotations: [sync, channel, warning, frame]
  - id: values
    desc: Values
    annotations: [channel-value]

## Decoding logic

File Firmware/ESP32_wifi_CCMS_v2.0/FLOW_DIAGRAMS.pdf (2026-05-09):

CCMS V2.0 Firmware - Mermaid Flow Diagrams
1. System Hardware Architecture
2. Main Software Execution Loop
3. Remote Control & AWS Shadow Delta Flow

# CCMS V2.0 Firmware - Mermaid Flow Diagrams

This file contains Mermaid.js diagrams illustrating the hardware architecture, main software execution loop, and the AWS Device Shadow data flow of the CCMS ESP32 V2.0 System.

You can view these diagrams natively in VS Code by installing a Markdown preview extension that supports Mermaid (like "Markdown Preview Mermaid Support"), or by pasting the code blocks into the Mermaid Live Editor. (https://mermaid.live/)

# 1. System Hardware Architecture

This diagram outlines the physical hardware topology, illustrating what is connected to the ESP32 and via which interfaces.

Parse error on line 26:
...Connections ESP <-->|Wi-Fi / mTLS| A ----------------------^
Expecting 'SEMI', 'NEWLINE', 'SPACE', 'EOF', '--', 'ARROW_POINT', 'ARROW_CIRCLE', 'ARROW_CROSS', 'ARROW_OPEN', '-.', 'DOTTED_ARROW_POINT', 'DOTTED_ARROW_CIRCLE', 'DOTTED_ARROW_CROSS', 'DOTTED_ARROW_OPEN', '==', 'THICK_ARROW_POINT', 'THICK_ARROW_CIRCLE', 'THICK_ARROW_CROSS', 'THICK_ARROW_OPEN', got 'TAGSTART'

# 2. Main Software Execution Loop

This flowchart visualizes the non-blocking execution thread running inside the loop() function of main.cpp.

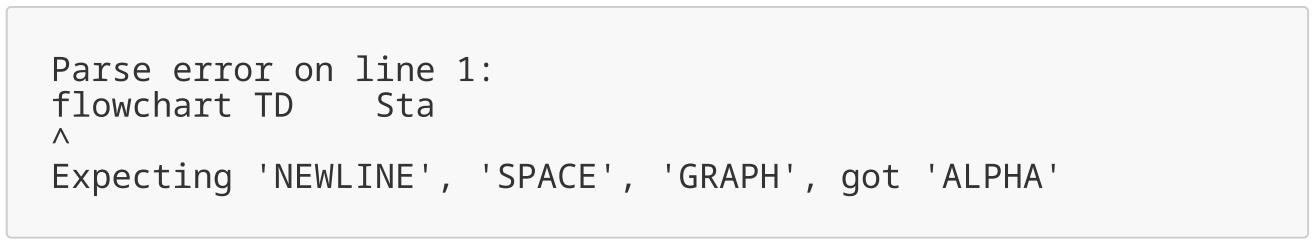
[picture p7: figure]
Parse error on line 1:; flowchart TD; Sta

Expecting 'NEWLINE', 'SPACE', 'GRAPH', got 'ALPHA'

# 3. Remote Control & AWS Shadow Delta Flow

This sequence diagram shows how remote control commands flow from the Cloud (AWS) down down to the end-node components.

Parse error on line 14:
...LAY_PIN, state) | end | alt JSON Co
----------------------^
Expecting 'SPACE', 'NL', 'participant', 'activate', 'deactivate', 'title', 'loop', 'opt', 'alt', 'else', 'par', 'note', 'ACTOR', got 'end'

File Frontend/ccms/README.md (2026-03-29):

## CCMS Portal Frontend

This app is a Next.js operator console scaffold for the CCMS AWS architecture.

### Routes

- `/login`: Captures the Dashboard and Admin keys.
- `/dashboard`: GET `/api/v1/dashboard/summary`
- `/panels`: GET `/api/v1/panels` with status, limit, and offset.
- `/panel?id={panelId}`: GET `/status` and POST `/command`.
- `/analytics`: GET `/api/v1/panels/{panelId}/telemetry?start=&end=`
- `/alerts`: GET `/api/v1/alerts?severity=` and PATCH `/api/v1/alerts/{alertId}`.

### Environment Variables

Copy `.env.example` values into your local `.env.local` and fill real values:

- `NEXT_PUBLIC_API_BASE_URL` (Set this to the Lambda API endpoint prefix)

### Notes

- Keys are held in `localStorage` client state and attached as `x-dashboard-key` and `x-admin-key` headers on API requests.
- Next.js is configured with static export mode (`output: "export"`), so Vercel can host this without Vercel serverless functions.

### Run

```bash
npm run dev
```

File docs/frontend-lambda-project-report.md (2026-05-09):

# Frontend and Lambda Project Report

## 1. Executive Summary

The CCMS portal is a serverless-first monitoring and command interface for distributed streetlight panels. The system combines:

- A Next.js 16 + React 19 frontend (operator console)
- AWS Lambda functions (API and ingestion)
- DynamoDB tables for metadata and telemetry
- AWS IoT + SQS pipeline (edge to cloud ingestion)

The frontend provides fleet visibility (dashboard, maps, analytics, alerts) and command operations (manual relay commands, RTC schedule updates, panel provisioning). Lambda functions expose authenticated CRUD and telemetry APIs, and ingest telemetry payloads from SQS into DynamoDB.

This report documents architecture, implementation details, data flow, auth model, API behavior, deployment assumptions, current risks, and recommendations.

## 2. Scope and Objectives

This report focuses specifically on:

- Frontend application in `ccms/`
- Lambda functions in `Lambda/`

Primary objectives:

- Describe how the frontend is structured and how each feature works
- Describe Lambda endpoint behavior, validation, and data persistence logic
- Document integration contracts between frontend and backend
- Identify implementation strengths, gaps, and production hardening needs

## 3. System Context

### 3.1 Logical Components

1. Edge meters publish telemetry to AWS IoT Core.
2. IoT rules deliver payloads (via SQS) to ingestion Lambda.
3. Ingestion Lambda writes telemetry into `MeterTelemetry` (DynamoDB).
4. API Lambda serves metadata, history, snapshot, and mutation endpoints over HTTP.
5. Frontend consumes API Lambda using key-based headers.

### 3.2 Data Stores

- `PanelMetadata` (DynamoDB): panel identity, status, location, firmware, and mutable configuration fields.
- `MeterTelemetry` (DynamoDB): time-series telemetry indexed by `meter_id` + `timestamp`.

## 4. Frontend Detailed Report

### 4.1 Technology Stack

- Framework: Next.js 16 (`output: "export"` static export)
- UI runtime: React 19
- Styling: Tailwind CSS v4 + HeroUI v3
- Visualization: Recharts
- Mapping: Leaflet + React Leaflet
- Date/time utils: date-fns
- Iconography: lucide-react

### 4.2 Application Architecture

Frontend is organized into three layers:

1. Route layer (`app/`)
   - Defines pages, user flows, and route-level state/effects.
2. Component layer (`components/`)
   - Shared shell, auth boundary, map widgets, and UI primitives.
3. API/data layer (`lib/api/`, `lib/auth/`)
   - Header auth injection, typed contracts, and backend-to-UI data shaping.

Because static export mode is enabled, the frontend is a static app that calls external APIs from the browser at runtime.

### 4.3 Authentication and Session Model

Auth is key-based and client-managed:

- Login captures `dashboardKey` (required) and `adminKey` (optional).
- Session is stored in localStorage (`ccms_dashboard_session`).
- API wrapper sends headers:
  - `x-dashboard-key` for all authenticated calls
  - `x-admin-key` when present (required by backend for mutating methods)

Role derivation is local:

- Admin when `adminKey` exists
- Operator when only dashboard key exists

Route protection:

- Console routes use `RequireAuth` wrapper to redirect unauthenticated users to `/login`.

### 4.4 Route and Feature Breakdown

#### 4.4.1 Landing (`/`)

- Branding/entry page with shortcuts to login and dashboard.

#### 4.4.2 Login (`/login`)

- Accepts dashboard and optional admin key.
- Stores keys via auth provider.
- Redirects authenticated users to dashboard.

#### 4.4.3 Dashboard (`/dashboard`)

- Fetches in parallel:
  - Fleet summary (derived from snapshot)
  - Panels list
  - Active alerts
- Shows KPI cards:
  - total nodes
  - active alarms
  - cluster avg voltage
  - frequency
  - total PF
  - estimated 24h energy
- Renders fleet health bar chart (online/offline/fault).
- Renders recent alert feed.

#### 4.4.4 Panels (`/panels`)

- Fleet inventory with:
  - status filter
  - search
  - sorting
  - pagination
  - 3 view modes: map / grid / table
- Uses dynamic map import to avoid SSR Leaflet constraints.
- Includes deep links to per-panel console page.

#### 4.4.5 Panel Details (`/panel?id=...`)

- Core command center per node.
- Polls live every 30 seconds and supports manual refresh.
- Loads:
  - current panel live status
  - time-range telemetry (`1H`, `24H`, `7D`)
  - panel metadata
- Features:
  - instant KPI strip
  - anomaly insights (voltage, PF, frequency thresholds)
  - historical charts
  - relay command dispatch (ON/OFF)
  - RTC schedule synchronization
  - map location card

#### 4.4.6 Manage Panel (`/manage-panel`)

- Create new panel or edit existing panel metadata.
- Supports geolocation and map-based coordinate picking.
- Enforces admin key for writes (prompts if absent in session).
- Uses POST for create, PATCH for update.

#### 4.4.7 Analytics (`/analytics`)

- Historical telemetry query across one or more panels.
- Date-range query form.
- Visualization modes:
  - Overview charts by metric
  - Multi-metric compare across selected nodes
  - Raw telemetry table
  - Custom chart builder (line/area/bar)
- CSV export of queried telemetry.

#### 4.4.8 Alerts (`/alerts`)

- Displays active/acknowledged alerts.
- Severity and status filters.
- Acknowledge action updates client-side alert state.

### 4.5 Frontend API Integration Design

`ccms/lib/api/http.ts` centralizes HTTP behavior:

- Reads `NEXT_PUBLIC_API_BASE_URL`
- Adds authentication headers from session store
- JSON serialization/parsing
- Unified error throw for non-2xx responses

`ccms/lib/api/ccms-api.ts` provides domain functions:

- Converts Lambda raw snapshot/history data into typed UI structures.
- Adds UI-level derived metrics and defaults.
- Isolates route components from backend response shape changes.

### 4.6 Data Contracts and Type System

`ccms/lib/api/types.ts` defines stable contracts used by UI screens:

- `DashboardSummary`
- `PanelRecord`, `PanelLiveStatus`
- `TelemetryPoint`, `TelemetryResponse`
- `AlertRecord`, `AlertListResponse`
- `PanelCommandPayload`

This helps avoid ad-hoc parsing in components and improves maintainability.

### 4.7 UI and UX Characteristics

- Dark industrial theme aligned with operations center use case.
- Shared UI primitives for consistency (headers, cards, banners, chips).
- Map interactions for spatial awareness.
- Soft real-time behavior through periodic refresh and user-triggered refresh.

### 4.8 Frontend Deployment Model

Because `next.config.ts` sets `output: "export"`:

- App can be hosted as static files (CDN/object storage/GitHub Pages-like setups).
- No Next.js server runtime required.
- API base URL must be externally reachable and configured via env var.

## 5. Lambda Functions Detailed Report

### 5.1 Lambda Inventory

1. `Lambda/lambdaAPI.py`
   - HTTP API handler for metadata, snapshot, history, and mutations.
2. `Lambda/saveDataFromSQStoDB,py`
   - SQS batch ingestion Lambda writing telemetry records to DynamoDB.

### 5.2 API Lambda (`lambdaAPI.py`) Behavior

#### 5.2.1 Initialization

- Creates clients/resources:
  - SSM client
  - DynamoDB resource
  - `MeterTelemetry` table object
  - `PanelMetadata` table object
- Configures root logger at INFO level.

#### 5.2.2 Security Model

Per-request key validation using SSM parameters:

- `/api/dashboard_key` (Level 1)
- `/api/admin_key` (Level 2)

Rules:

- All requests require valid dashboard key.
- Mutating methods (`POST`, `PUT`, `PATCH`, `DELETE`) require valid admin key.

#### 5.2.3 CORS

Always returns permissive CORS headers:

- `Access-Control-Allow-Origin: *`
- Allowed headers include dashboard/admin keys.

`OPTIONS` returns `200` for browser preflight.

#### 5.2.4 Endpoint Logic by Method

`GET`

- `?enquiry=history`
  - Validates panel id and timestamp range.
  - Queries `MeterTelemetry` by `meter_id` and timestamp range.
  - Returns ordered time-series points.

- `?enquiry=snapshot`
  - Scans all `PanelMetadata` records.
  - For each panel, queries latest 5 telemetry records.
  - Returns array of `{ metadata, recent_logs }`.

- default metadata read
  - Requires `panel_id` in query or body.
  - Performs `get_item` on `PanelMetadata`.

`POST` / `PUT`

- Requires body with `panel_id`.
- Writes full item into `PanelMetadata` (`put_item`).

`PATCH`

- Requires target `panel_id` and at least one update field.
- Dynamically builds update expression and patches selected fields.

`DELETE`

- Validates existence and deletes panel metadata entry.

#### 5.2.5 Validation and Error Handling

- JSON body parse guard with 400 on malformed JSON.
- Input validation helpers for panel id and timestamps.
- Maps DynamoDB errors to user-facing HTTP codes/messages where possible.
- Top-level exception fallback returns 500 with generic message.

#### 5.2.6 JSON Serialization

Uses custom `DecimalEncoder` to convert DynamoDB Decimal values before response serialization.

### 5.3 Ingestion Lambda (`saveDataFromSQStoDB,py`) Behavior

#### 5.3.1 Trigger and Batch Handling

- Triggered by SQS event with `Records` batch.
- Iterates each message independently.
- Returns `batchItemFailures` for partial retry semantics.

#### 5.3.2 Record Processing

For each message:

1. Parse JSON payload with `parse_float=Decimal`
2. Resolve partition key:
   - `meter_id = payload.client_id` (fallback `UNKNOWN_METER`)
3. Resolve timestamp sort key:
   - `server_time` preferred, else `timestamp`, cast to int
4. Copy remaining telemetry fields into DynamoDB item
5. `put_item` into `MeterTelemetry`

#### 5.3.3 Failure Behavior

- Any record-level exception logs failure and appends message id to batch failures.
- Failed messages remain in queue for retry.

### 5.4 Operational Characteristics of Lambda Layer

Strengths:

- Clear separation between API and ingestion responsibilities.
- Admin/user authorization split.
- Explicit validation path for critical query params.
- Partial batch retry handling in ingestion path.

Constraints:

- Snapshot uses table scan + per-panel query, which can become expensive at scale.
- Key-based auth is shared-secret style and lacks rotation/session semantics in API design.

## 6. Frontend <-> Lambda Integration Contracts

### 6.1 Required Environment

Frontend requires:

- `NEXT_PUBLIC_API_BASE_URL`

Runtime behavior assumes endpoint paths like:

- `DashboardAPIHandler?enquiry=snapshot`
- `DashboardAPIHandler?enquiry=history&panel_id=...`

### 6.2 Header Contract

- Required for all API calls: `x-dashboard-key`
- Required for mutations: `x-admin-key`

### 6.3 Core Functional Mappings

- Dashboard, panels, alerts all derive from `enquiry=snapshot`.
- Panel command writes call API `PATCH` with desired state/schedule fields.
- Analytics/history calls use `enquiry=history` + timestamp range.

## 8. Testing and Verification

### 8.1 Existing Test Artifacts

- `Lambda/TestEndpoints/getData.js` demonstrates API usage patterns.
- Frontend:
- Unit tests for API mapper functions (`ccms-api.ts`)
- Route-level integration tests for auth redirects and mutation flows
- E2E tests for login -> dashboard -> panel command paths

Lambda API:

- Contract tests by method and auth level
- Validation tests for timestamp and panel_id edge cases
- Error mapping tests for DynamoDB and SSM failures

Ingestion Lambda:

- Batch tests with mixed good/bad records
- Type consistency tests for timestamp and meter id
- Idempotency/duplication handling checks

## 9. Deployment and Operations Notes

Frontend:

- Build: `npm run build` in `ccms/`
- Host generated static output on CDN/static hosting
- Ensure API URL and CORS are configured correctly

Lambda:

- Confirm SSM parameters exist (`/api/dashboard_key`, `/api/admin_key`)
- Confirm table names match deployed DynamoDB resources
- Verify IAM permissions for:
  - SSM `GetParameters`
  - DynamoDB read/write on both tables

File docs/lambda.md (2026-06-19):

# Lambda Backend

Python AWS Lambda functions deployed behind API Gateway that handle REST API endpoints, authentication, and SQS-based telemetry ingestion for the CCMS system.

---

## Lambda Inventory

| Function | File | Trigger | Purpose |
|---|---|---|---|
| **API Lambda** | `Lambda/lambdaAPI.py` | API Gateway (HTTP) | REST API for dashboard snapshot, panel status, history, provisioning, and commands |
| **Ingestion Lambda** | `Lambda/saveDataFromSQStoDB,py` | SQS | Writes incoming telemetry from edge devices into DynamoDB |

---

## API Lambda (`lambdaAPI.py`)

### Initialization

On cold start, the Lambda creates:

- **SSM client** — for retrieving auth keys from Parameter Store
- **DynamoDB resource** — connected to `MeterTelemetry` and `PanelMetadata` tables
- **IoT Data client** — for publishing MQTT commands to AWS IoT Device Shadow

### Security Model

Two-level key-based authentication using AWS SSM Parameter Store:

| Level | Key | SSM Parameter | Required For |
|---|-----|---|---|
| 1 — Dashboard | `x-dashboard-key` | `/api/dashboard_key` | All requests |
| 2 — Admin | `x-admin-key` | `/api/admin_key` | Mutations (POST, PUT, PATCH, DELETE) |

Keys are validated on every request. Invalid/missing keys return `401` (dashboard) or `403` (admin).

### CORS

Always returns permissive headers:

```http
Access-Control-Allow-Origin: *
Access-Control-Allow-Headers: Content-Type, x-dashboard-key, x-admin-key, Authorization
Access-Control-Allow-Methods: OPTIONS, GET, POST, PUT, PATCH, DELETE
```

`OPTIONS` preflight requests return `200`.

### API Endpoints

#### `GET` — Read Operations

| Query | Required Params | Description | Response |
|---|---|---|---|
| `?enquiry=snapshot` | None | Scans all `PanelMetadata` + latest 5 telemetry records per panel | `[{ metadata, recent_logs }]` |
| `?enquiry=history` | `panel_id`, `start`, `end` | Queries `MeterTelemetry` by meter ID and timestamp range | `[{ ...telemetry fields }]` |
| *(no enquiry)* | `panel_id` | Gets single panel metadata from `PanelMetadata` | `{ ...panel fields }` |

**Snapshot Endpoint** (`?enquiry=snapshot`):

1. Performs `scan()` on `PanelMetadata` table
2. For each panel, queries `MeterTelemetry` with `ScanIndexForward=False` and `Limit=5`
3. Returns combined array of `{ metadata, recent_logs }`

**History Endpoint** (`?enquiry=history`):

1. Validates panel_id (required, non-empty)
2. Validates timestamps (non-negative integers, start ≤ end)
3. Timestamps are zero-padded to 13 digits for lexicographic DynamoDB sort key matching
4. Queries `MeterTelemetry` by `meter_id` and `timestamp` range with `ScanIndexForward=True`

#### `POST` / `PUT` — Provisioning (Admin Only)

- Requires request body with `panel_id`
- Writes entire item to `PanelMetadata` via `put_item()`
- Returns `201` on success

#### `PATCH` — Surgical Updates (Admin Only)

Handles three command types:

| Command Type | Body Fields | Behavior |
|---|---|---|
| **Relay Control** | `{ desired_state: true/false }` | Updates DynamoDB + publishes MQTT `relay_state` to shadow |
| **Schedule Update** | `{ schedule: { startLocalTime, endLocalTime } }` | Updates DynamoDB + publishes MQTT schedule to shadow |
| **Shadow Keys** | `{ relay_state, device_state, timeToAutoTurnOn, timeToAutoTurnOff }` | Updates DynamoDB + publishes all shadow keys via MQTT |

MQTT commands are published to `$aws/things/{device_id}/shadow/update` with the format:

```json
{
  "state": {
    "desired": {
      "relay_state": true
    }
  }
}
```

The function resolves `device_id` from the `PanelMetadata` table or falls back to the panel ID.

#### `DELETE` — Decommission (Admin Only)

- Validates panel exists (returns `404` if not found)
- Deletes item from `PanelMetadata` via `delete_item()`
- Returns `200` on success

### Error Handling

| Scenario | HTTP Status |
|---|---|
| Malformed JSON body | `400` |
| Missing/invalid panel_id | `400` |
| Invalid timestamps | `400` |
| Panel not found | `404` |
| Missing dashboard key | `401` |
| Missing admin key (on mutation) | `403` |
| DynamoDB `ValidationException` | `400` |
| DynamoDB `ResourceNotFoundException` | `404` |
| General DynamoDB error | `500` |
| Catch-all exception | `500` |

### JSON Serialization

Uses a custom `DecimalEncoder` class to convert DynamoDB `Decimal` types to `float` for JSON-compatible output.

---

## Ingestion Lambda (`saveDataFromSQStoDB.py`)

### Trigger

- Event source: **SQS queue** (messages from AWS IoT Rules Engine)
- Batch processing: iterates all records in the SQS event

### Record Processing

For each SQS message:

1. **Parse JSON** — loads payload with `parse_float=Decimal` for DynamoDB compatibility
2. **Resolve partition key** — `meter_id = payload.client_id` (falls back to `UNKNOWN_METER`)
3. **Resolve sort key** — `timestamp = int(payload.server_time)` (falls back to `payload.timestamp` or `0`)
4. **Build item** — copies all remaining payload fields into the DynamoDB item
5. **Write** — `put_item()` into `MeterTelemetry` table

### Partial Batch Failure

- On any record-level exception, logs the error and appends `messageId` to `batchItemFailures`
- Failed messages remain in SQS for retry (up to the queue's configured max retries)
- Successful records are removed from the queue

### DynamoDB Schema

**`MeterTelemetry`** table:

| Attribute | Key Type | Source | Notes |
|---|---|---|---|
| `meter_id` | Partition Key | `payload.client_id` | String |
| `timestamp` | Sort Key | `payload.server_time` | Integer (epoch ms) |
| *(all other fields)* | - | Copied from payload | Modbus registers, status fields, etc. |

**`PanelMetadata`** table:

| Attribute | Key Type | Source | Notes |
|---|---|---|---|
| `panel_id` | Partition Key | Body/query parameter | String |
| *(all other fields)* | - | From API request | Location, status, config, etc. |

---

## IAM Permissions Required

Both Lambdas require:

- `dynamodb:GetItem`, `dynamodb:PutItem`, `dynamodb:UpdateItem`, `dynamodb:DeleteItem`, `dynamodb:Query`, `dynamodb:Scan` on target tables
- `ssm:GetParameters` on `/api/dashboard_key` and `/api/admin_key` (API Lambda only)
- `iotdata:Publish` on IoT topics (API Lambda only, for MQTT commands)

---

## Local Testing

A Node.js test script is provided at `Lambda/TestEndpoints/getData.js`:

```bash
cd Lambda/TestEndpoints
npm install
node getData.js
```

This script demonstrates authenticated API calls to the deployed Lambda endpoints.

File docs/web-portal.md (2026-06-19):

# Web Portal

The operator console is a **Next.js 16** application with static export (`output: "export"`) that provides a real-time fleet management interface for streetlight monitoring and control.

Fleet Overview

Panel Command Center

---

## Technology Stack

| Layer | Technology |
|---|---|
| Framework | Next.js 16 (`output: "export"`) |
| UI Runtime | React 19 |
| UI Components | HeroUI v3 |
| Styling | Tailwind CSS v4 |
| Charts | Recharts |
| Maps | Leaflet + React-Leaflet |
| Animations | Framer Motion |
| Icons | Lucide React |
| Dates | date-fns |
| Languages | TypeScript |

## Project Structure

```
ccms/
├── app/                          ← Route definitions and pages
│   ├── page.tsx                  ← Landing page
│   ├── layout.tsx                ← Root layout
│   ├── providers.tsx             ← Client-side providers (auth, HeroUI)
│   ├── globals.css               ← Global styles + Tailwind
│   ├── login/page.tsx            ← Authentication page
│   └── (console)/
│       ├── layout.tsx            ← Console layout with AppShell
│       ├── dashboard/page.tsx    ← Fleet summary dashboard
│       ├── panels/page.tsx       ← Panel inventory (map/grid/table)
│       ├── panel/page.tsx        ← Single panel detail + commands
│       ├── manage-panel/page.tsx ← Panel provisioning/editing
│       ├── analytics/page.tsx    ← Historical telemetry viewer
│       └── alerts/page.tsx       ← Alert management
├── components/                   ← Shared React components
│   ├── app-shell.tsx             ← Console navigation shell
│   ├── auth-provider.tsx         ← Auth context + localStorage management
│   ├── require-auth.tsx          ← Route guard wrapper
│   ├── fleet-map.tsx             ← Map view of all panels
│   ├── location-picker-map.tsx   ← GPS coordinate picker for provisioning
│   └── ui.tsx                    ← Shared UI primitives
└── lib/
    ├── api/
    │   ├── http.ts               ← HTTP client with auth header injection
    │   ├── ccms-api.ts           ← Domain API functions (snapshot, history, commands)
    │   └── types.ts              ← TypeScript type definitions
    ├── auth/
    │   └── session-store.ts      ← localStorage session read/write
    ├── alert-generator.ts        ← Client-side alert simulation/mapping
    └── register-map.json         ← Default GPS coordinates for registration
```

## Routes

| Route | Description | API Dependencies |
|---|---|---|
| `/` | Landing page with branding and login/dashboard links | None |
| `/login` | Two-field form (Dashboard Key, Admin Key); stores in localStorage | None (client-only) |
| `/dashboard` | Fleet KPI cards, health bar chart, recent alerts | `DashboardAPIHandler?enquiry=snapshot` |
| `/panels` | Fleet inventory with status filter, search, sort, pagination; 3 view modes (map/grid/table) | `DashboardAPIHandler?enquiry=snapshot` |
| `/panel?id={panelId}` | Live status polling, command dispatch (relay ON/OFF, RTC schedule, shadow keys), telemetry charts (1H/24H/7D), anomaly insights | `enquiry=snapshot` + `enquiry=history` |
| `/manage-panel` | Create new panel or edit existing; GPS map picker; requires admin key | `POST`/`PATCH` to `DashboardAPIHandler` |
| `/analytics` | Multi-panel historical telemetry; charts, compare mode, raw data table, CSV export | `enquiry=history` |
| `/alerts` | Alert list with severity/status filters; acknowledge action | `enquiry=snapshot` (derived from fault panels) |

## Authentication

Auth is **key-based** and fully client-managed:

1. **Login page** captures:
   - `dashboardKey` (required) — sent as `x-dashboard-key` header
   - `adminKey` (optional) — sent as `x-admin-key` header; required for mutations
2. Session is stored in `localStorage` under `ccms_dashboard_session`.
3. Role is derived client-side:
   - **Admin** — when `adminKey` is present
   - **Operator** — when only `dashboardKey` is present
4. Route protection via `<RequireAuth>` wrapper redirects unauthenticated users to `/login`.
5. The `AppShell` component displays role chip and logout button in the header.

## API Integration

All backend calls go through a centralized HTTP client (`lib/api/http.ts`):

- Reads `NEXT_PUBLIC_API_BASE_URL` environment variable
- Injects `x-dashboard-key` and `x-admin-key` headers from session
- Handles JSON serialization/deserialization
- Throws on non-2xx responses

Domain logic is encapsulated in `lib/api/ccms-api.ts`, which:

- Transforms Lambda raw snapshot/history data into typed UI structures
- Computes derived metrics (e.g., estimated 24h energy from current fleet load)
- Isolates UI components from backend response shape changes

## Components

### AppShell
The console layout wrapper providing:
- Header with "CCMS Command Console" branding and role chip
- Navigation tabs: Dashboard, Panels, Analytics, Alerts
- Active route highlighting with glow effect
- Responsive design with max-width container

### FleetMap
Dynamic Leaflet map showing all panel locations with:
- Color-coded markers by status (Online/Offline/Fault)
- Popups with panel name, status, and link to detail page
- Dynamically imported to avoid SSR Leaflet issues

### LocationPickerMap
Used in panel registration for GPS coordinate selection:
- Click-to-set marker on map
- Returns latitude/longitude for form submission

### RequireAuth
Route guard that:
- Checks for valid session on mount
- Redirects to `/login` if unauthenticated
- Wraps all console routes

## Running Locally

```bash
cd ccms
npm install
npm run dev        # Development server at http://localhost:3000
npm run build      # Static export to ccms/out/
```

### Environment Variables

```env
NEXT_PUBLIC_API_BASE_URL=https://your-api-gateway-endpoint.execute-api.region.amazonaws.com/prod/
```

Copy values into `ccms/.env.local`.

## Deployment

Since `output: "export"` is configured in `next.config.ts`:

- The app builds entirely static files into `ccms/out/`
- Can be hosted on any static hosting (CDN, S3, GitHub Pages, Vercel without server functions)
- API base URL must be externally reachable and configured at build time

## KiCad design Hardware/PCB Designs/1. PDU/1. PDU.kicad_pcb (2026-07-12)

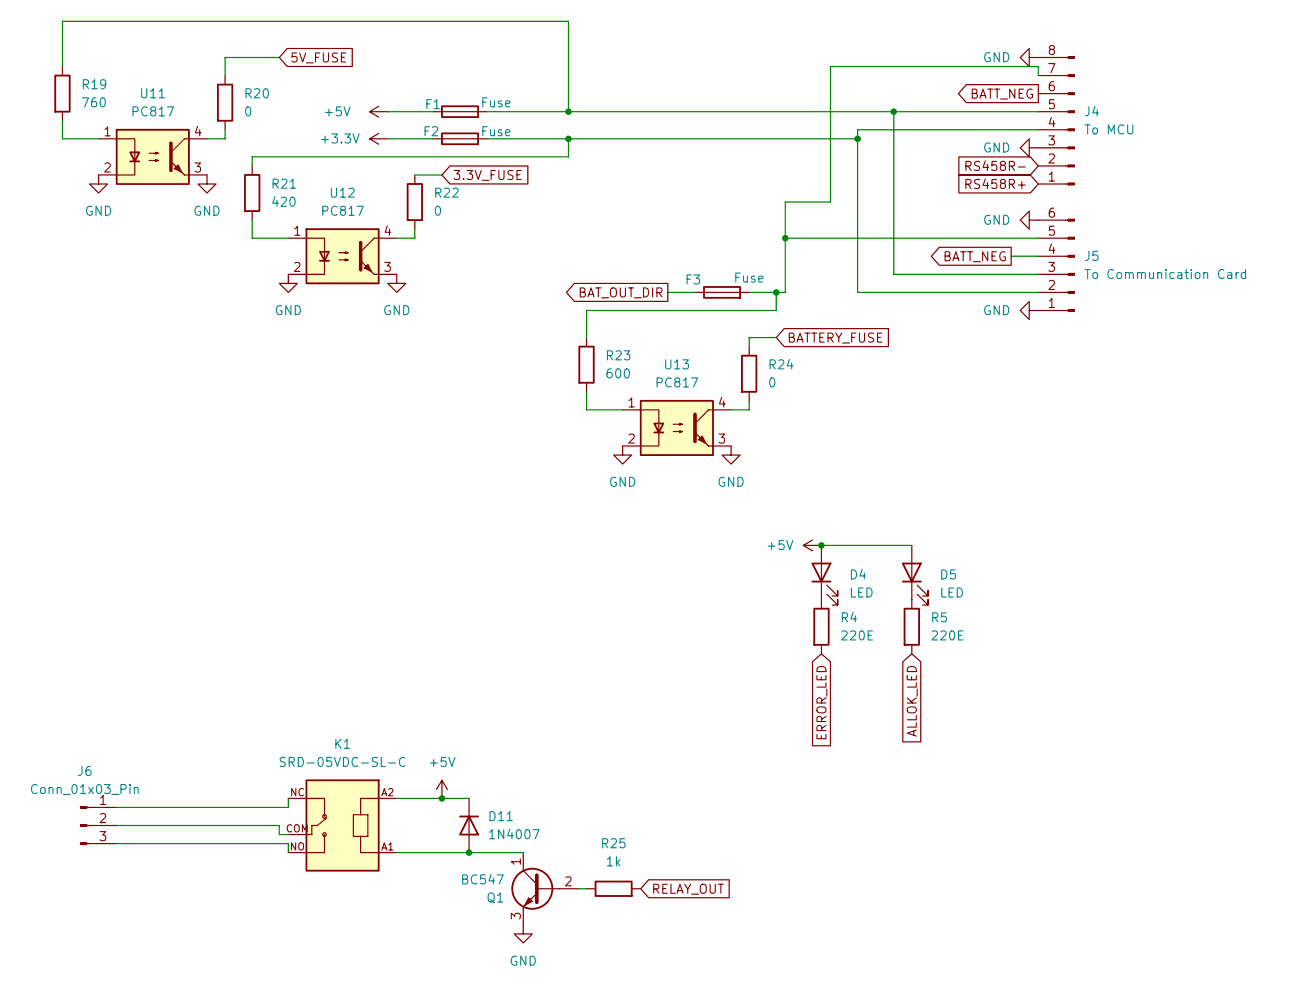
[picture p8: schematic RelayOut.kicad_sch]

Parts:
D4, D5: LED; LED_0402_1005Metric
D11: 1N4007; D_DO-41_SOD81_P10.16mm_Horizontal
F1, F2, F3: Fuse; Fuseholder_Blade_Mini_Keystone_3568
J4: To MCU; JST_XH_S8B-XH-A-1_1x08_P2.50mm_Horizontal
J5: To Communication Card; JST_XH_S6B-XH-A-1_1x06_P2.50mm_Horizontal
J6: Conn_01x03_Pin; PhoenixContact_MC_1,5_3-G-5.08_1x03_P5.08mm_Horizontal
K1: SRD-05VDC-SL-C; RELAY_SRD-05VDC-SL-C
Q1: BC547; TO-92_Inline
R4, R5: 220E; R_0805_2012Metric
R19: 760; R_0805_2012Metric
R20, R22, R24: 0; R_0805_2012Metric
R21: 420; R_0805_2012Metric
R23: 600; R_0805_2012Metric
R25: 1k; R_0805_2012Metric
U11, U12, U13: PC817; DIP-4_W7.62mm

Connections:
3.3V_FUSE: R22.1; also elsewhere on the board
5V_FUSE: R20.1; also elsewhere on the board
+3.3V: F2.1; also elsewhere on the board
+5V: D4.2 (A), D5.2 (A), D11.1 (K), F1.1, K1.A2; also elsewhere on the board
ALLOK_LED: R5.2; also elsewhere on the board
BATTERY_FUSE: R24.1; also elsewhere on the board
BATT_NEG: J4.6, J5.4; also elsewhere on the board
BAT_OUT_DIR: F3.1; also elsewhere on the board
ERROR_LED: R4.2; also elsewhere on the board
GND: J4.3, J4.8, J5.1, J5.6, Q1.3 (E), U11.2, U11.3, U12.2, U12.3, U13.2, U13.3; also elsewhere on the board
unnamed: D4.1 (K), R4.1
unnamed: D5.1 (K), R5.1
unnamed: D11.2 (A), K1.A1, Q1.1 (C)
unnamed: F2.2, J4.4, J5.2, R21.1
unnamed: F1.2, J4.5, J5.3, R19.1
unnamed: F3.2, J4.7, J5.5, R23.1
unnamed: J6.1, K1.NC
unnamed: J6.2, K1.COM
unnamed: J6.3, K1.NO
unnamed: Q1.2 (B), R25.1
unnamed: R19.2, U11.1
unnamed: R20.2, U11.4
unnamed: R21.2, U12.1
unnamed: R22.2, U12.4
unnamed: R23.2, U13.1
unnamed: R24.2, U13.4
RELAY_OUT: R25.2; also elsewhere on the board
RS458R+: J4.1; also elsewhere on the board
RS458R-: J4.2; also elsewhere on the board

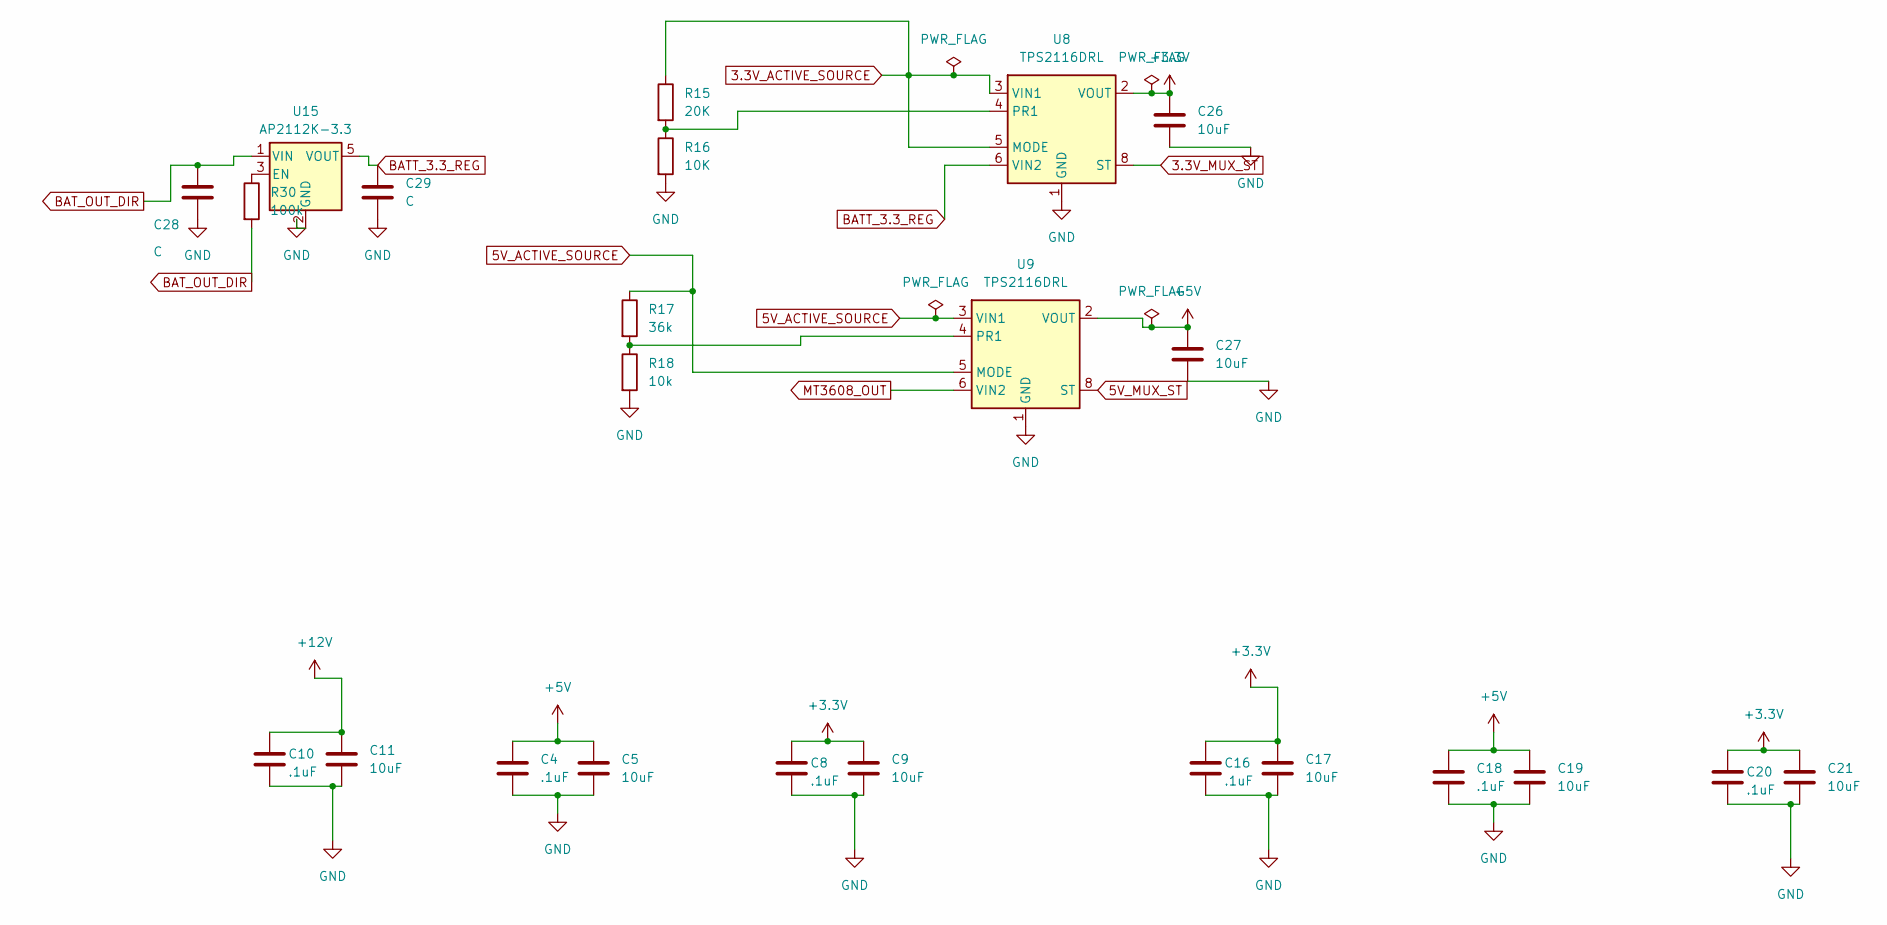
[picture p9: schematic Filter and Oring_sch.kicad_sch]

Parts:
C4, C8, C10, C16, C18, C20: .1uF; C_0805_2012Metric
C5, C9, C11, C17, C19, C21, C26, C27: 10uF; C_0805_2012Metric
C28, C29: C; C_0805_2012Metric
R15: 20K; R_0402_1005Metric
R16: 10K; R_0402_1005Metric
R17: 36k; R_0402_1005Metric
R18: 10k; R_0402_1005Metric
R30: 100k; R_0805_2012Metric
U8, U9: TPS2116DRL; SOT-583-8
U15: AP2112K-3.3; SOT-23-5

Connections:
3.3V_ACTIVE_SOURCE: R15.1, U8.3 (VIN1), U8.5 (MODE); also elsewhere on the board
3.3V_MUX_ST: U8.8 (ST); also elsewhere on the board
5V_ACTIVE_SOURCE: R17.1, U9.3 (VIN1), U9.5 (MODE); also elsewhere on the board
5V_MUX_ST: U9.8 (ST); also elsewhere on the board
+3.3V: C8.1, C9.1, C16.1, C17.1, C20.1, C21.1, C26.1, U8.2 (VOUT), U8.7 (VOUT); also elsewhere on the board
+5V: C4.1, C5.1, C18.1, C19.1, C27.1, U9.2 (VOUT), U9.7 (VOUT); also elsewhere on the board
+12V: C10.1, C11.1; also elsewhere on the board
BATT_3.3_REG: C29.1, U8.6 (VIN2), U15.5 (VOUT)
BAT_OUT_DIR: C28.1, R30.2, U15.1 (VIN); also elsewhere on the board
GND: C4.2, C5.2, C8.2, C9.2, C10.2, C11.2, C16.2, C17.2, C18.2, C19.2, C20.2, C21.2, C26.2, C27.2, C28.2, C29.2, R16.2, R18.2, U8.1 (GND), U9.1 (GND), U15.2 (GND); also elsewhere on the board
MT3608_OUT: U9.6 (VIN2); also elsewhere on the board
unnamed: R15.2, R16.1, U8.4 (PR1)
unnamed: R17.2, R18.1, U9.4 (PR1)
unnamed: R30.1, U15.3 (EN)

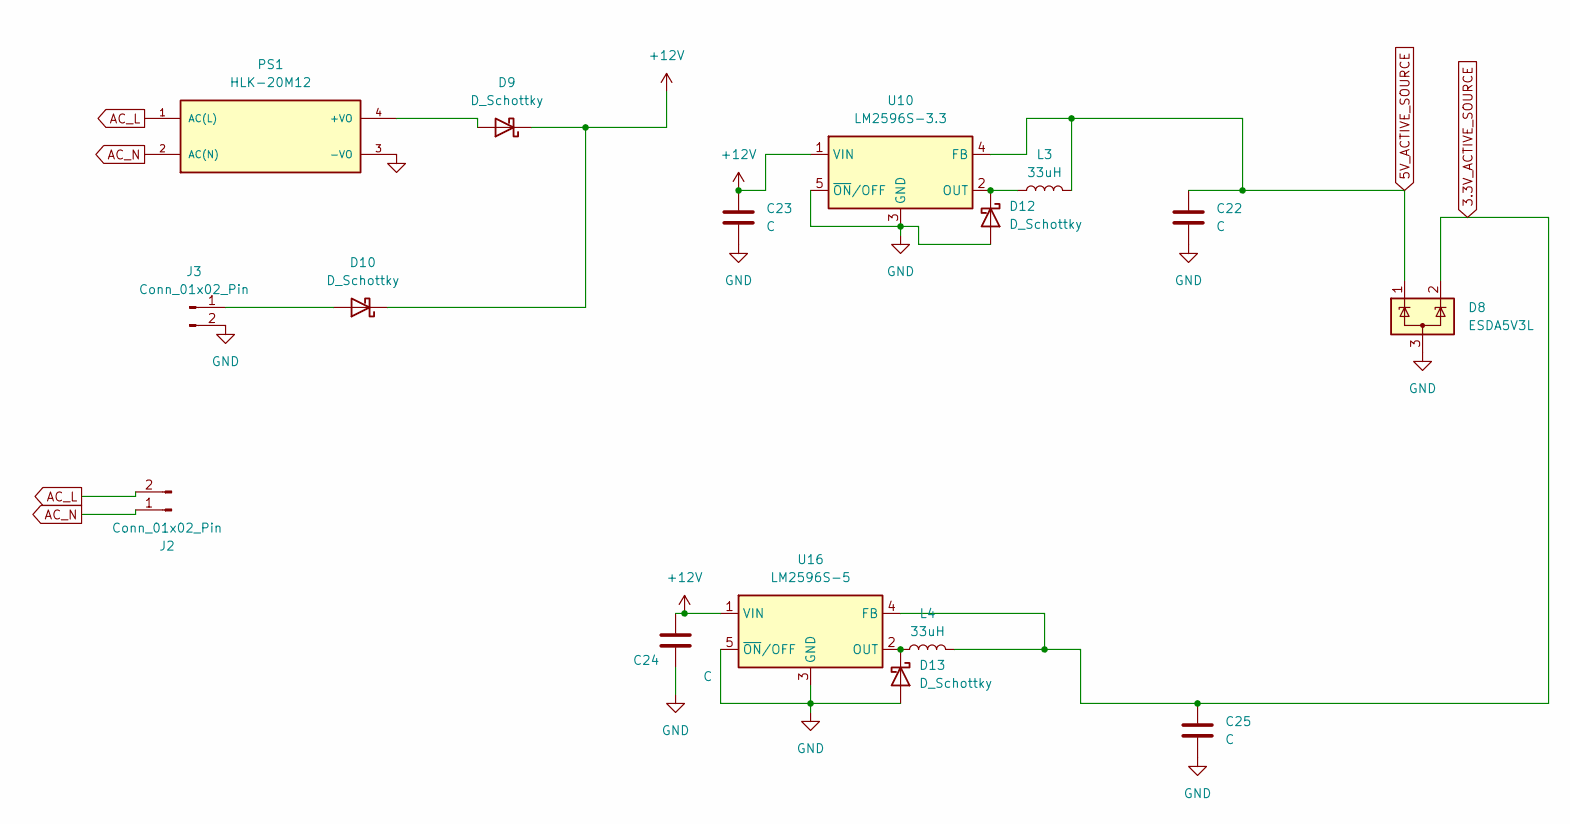
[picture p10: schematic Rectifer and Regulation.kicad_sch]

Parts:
C22, C23, C24, C25: C; C_0805_2012Metric
D8: ESDA5V3L; SOT-23-3
D9, D10: D_Schottky; D_SMC_Handsoldering
D12, D13: D_Schottky; D_3220_8050Metric
J2: Conn_01x02_Pin; PhoenixContact_MSTB_2,5_2-GF_1x02_P5.00mm_Horizontal_Thread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
J3: Conn_01x02_Pin; Molex_KK-254_AE-6410-02A_1x02_P2.54mm_Vertical
L3, L4: 33uH; L_10.4x10.4_H4.8
PS1: HLK-20M12; CONV_HLK-20M12; PARTREV V1.3
U10: LM2596S-3.3; TO-263-5_TabPin3
U16: LM2596S-5; TO-263-5_TabPin3

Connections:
3.3V_ACTIVE_SOURCE: C25.1, D8.2 (K), L4.2, U16.4 (FB); also elsewhere on the board
5V_ACTIVE_SOURCE: C22.1, D8.1 (K), L3.2, U10.4 (FB); also elsewhere on the board
+12V: C23.1, C24.1, D9.1 (K), D10.1 (K), U10.1 (VIN), U16.1 (VIN); also elsewhere on the board
AC_L: J2.2, PS1.1 (AC(L))
AC_N: J2.1, PS1.2 (AC(N))
GND: C22.2, C23.2, C24.2, C25.2, D8.3 (A), D12.2 (A), D13.2 (A), J3.2, PS1.3 (-VO), U10.3 (GND), U10.5 (~ON/OFF), U16.3 (GND), U16.5 (~ON/OFF); also elsewhere on the board
unnamed: D9.2 (A), PS1.4 (+VO)
unnamed: D10.2 (A), J3.1
unnamed: D12.1 (K), L3.1, U10.2 (OUT)
unnamed: D13.1 (K), L4.1, U16.2 (OUT)

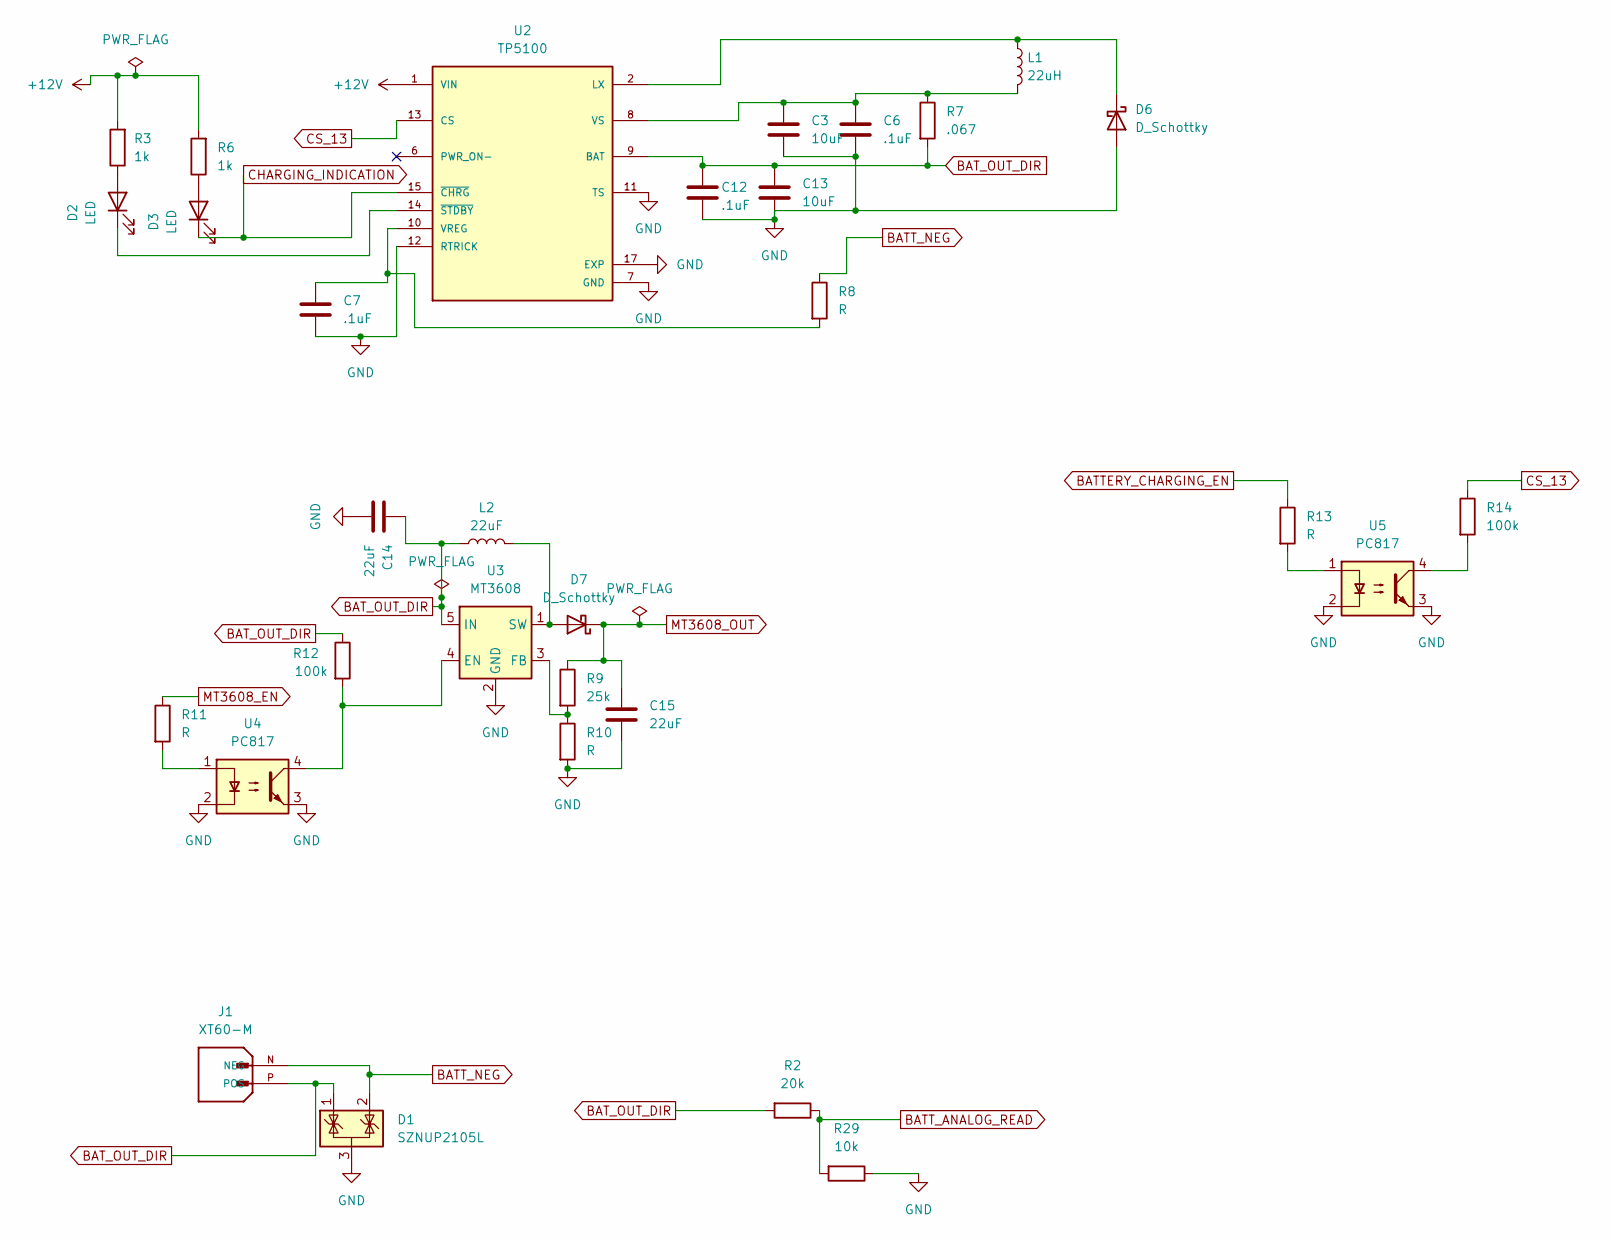
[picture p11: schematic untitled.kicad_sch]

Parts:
C3, C13: 10uF; C_0805_2012Metric
C6, C7, C12: .1uF; C_0805_2012Metric
C14, C15: 22uF; C_0805_2012Metric
D1: SZNUP2105L; SOT-23
D2, D3: LED; LED_0805_2012Metric
D6: D_Schottky; D_SMA
D7: D_Schottky; D_0805_2012Metric
J1: XT60-M; AMASS_XT60-M; PARTREV V1.2
L1: 22uH; L_Bourns-SRN6028
L2: 22uF; L_Coilcraft_XAL6060-XXX
R2: 20k; R_0805_2012Metric
R3, R6: 1k; R_0805_2012Metric
R7: .067; R_1206_3216Metric
R8, R10, R11, R13: R; R_0805_2012Metric
R9: 25k; R_0612_1632Metric_Pad1.18x3.40mm_HandSolder
R12, R14: 100k; R_0805_2012Metric
R29: 10k; R_0805_2012Metric
U2: TP5100; QFN65P400X400X90-17N; PARTREV 2.3
U3: MT3608; SOT-23-6
U4, U5: PC817; DIP-4_W7.62mm

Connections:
+12V: R3.2, R6.2, U2.1 (VIN), U2.4 (VIN), U2.5 (VIN), U2.16 (VIN); also elsewhere on the board
BATTERY_CHARGING_EN: R13.1; also elsewhere on the board
BATT_ANALOG_READ: R2.1, R29.2; also elsewhere on the board
BATT_NEG: D1.2 (K), J1.N (NEG), R8.1; also elsewhere on the board
BAT_OUT_DIR: C12.1, C13.1, C14.1, D1.1 (K), J1.P (POS), L2.1, R2.2, R7.2, R12.1, U2.9 (BAT), U3.5 (IN); also elsewhere on the board
CHARGING_INDICATION: D3.1 (K), U2.15 (~CHRG); also elsewhere on the board
CS_13: R14.1, U2.13 (CS)
GND: C3.2, C6.2, C7.2, C12.2, C13.2, C14.2, C15.2, D1.3 (A), D6.2 (A), R10.2, R29.1, U2.7 (GND), U2.11 (TS), U2.12 (RTRICK), U2.17 (EXP), U3.2 (GND), U4.2, U4.3, U5.2, U5.3; also elsewhere on the board
MT3608_EN: R11.1; also elsewhere on the board
MT3608_OUT: C15.1, D7.1 (K), R9.1; also elsewhere on the board
unnamed: D2.2 (A), R3.1
unnamed: D2.1 (K), U2.14 (~STDBY)
unnamed: D3.2 (A), R6.1
unnamed: D6.1 (K), L1.1, U2.2 (LX), U2.3 (LX)
unnamed: D7.2 (A), L2.2, U3.1 (SW)
unnamed: R11.2, U4.1
unnamed: R13.2, U5.1
unnamed: R14.2, U5.4
unnamed: C7.1, R8.2, U2.10 (VREG)
unnamed: C3.1, C6.1, L1.2, R7.1, U2.8 (VS)
unnamed: R12.2, U3.4 (EN), U4.4
unnamed: R9.2, R10.1, U3.3 (FB)

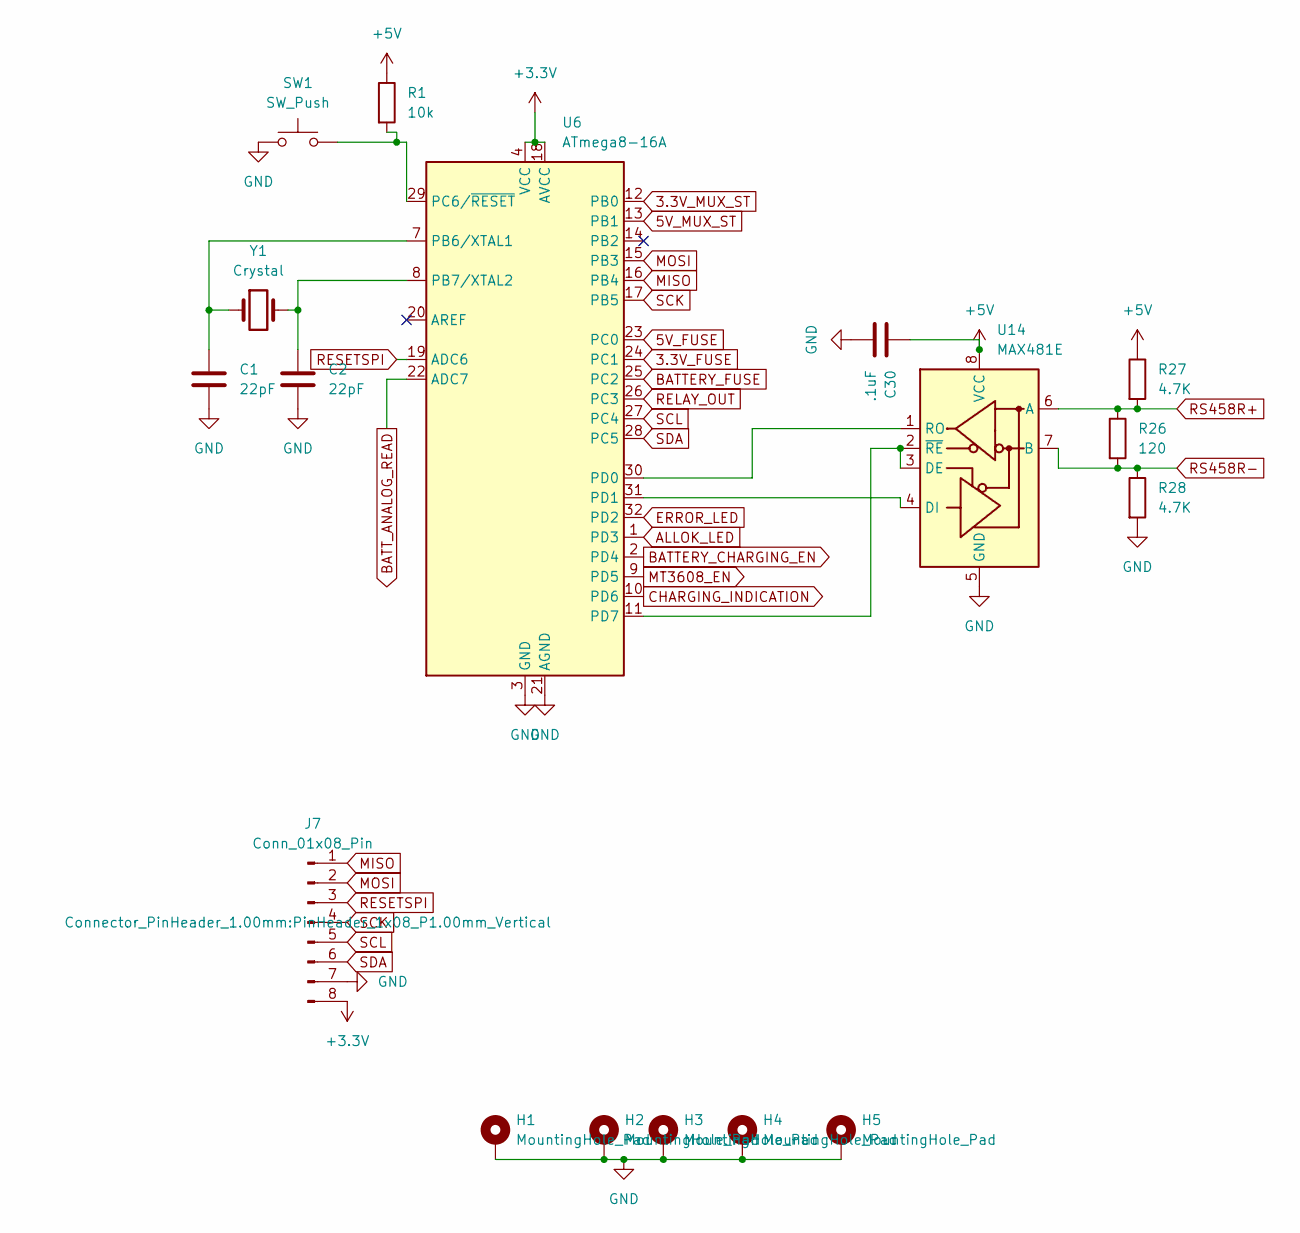
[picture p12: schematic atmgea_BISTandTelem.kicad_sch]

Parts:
C1, C2: 22pF; C_0805_2012Metric
C30: .1uF; C_0805_2012Metric
H1, H2, H3, H4, H5: MountingHole_Pad; MountingHole_3.2mm_M3_ISO7380_Pad
J7: Conn_01x08_Pin; PinHeader_1x08_P1.00mm_Vertical
R1: 10k; R_0805_2012Metric
R26: 120; R_0402_1005Metric
R27, R28: 4.7K; R_0805_2012Metric
SW1: SW_Push; SW_PUSH_6mm
U6: ATmega8-16A; TQFP-32_7x7mm_P0.8mm
U14: MAX481E; SOIC-8_3.9x4.9mm_P1.27mm
Y1: Crystal; Crystal_HC49-U_Vertical

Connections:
3.3V_FUSE: U6.24 (PC1); also elsewhere on the board
3.3V_MUX_ST: U6.12 (PB0); also elsewhere on the board
5V_FUSE: U6.23 (PC0); also elsewhere on the board
5V_MUX_ST: U6.13 (PB1); also elsewhere on the board
+3.3V: J7.8, U6.4 (VCC), U6.6 (VCC), U6.18 (AVCC); also elsewhere on the board
+5V: C30.1, R1.1, R27.1, U14.8 (VCC); also elsewhere on the board
ALLOK_LED: U6.1 (PD3); also elsewhere on the board
BATTERY_CHARGING_EN: U6.2 (PD4); also elsewhere on the board
BATTERY_FUSE: U6.25 (PC2); also elsewhere on the board
BATT_ANALOG_READ: U6.22 (ADC7); also elsewhere on the board
CHARGING_INDICATION: U6.10 (PD6); also elsewhere on the board
ERROR_LED: U6.32 (PD2); also elsewhere on the board
GND: C1.2, C2.2, C30.2, H1.1 (1_1), H2.1 (1_1), H3.1 (1_1), H4.1 (1_1), H5.1 (1_1), J7.7, R28.2, SW1.1, U6.3 (GND), U6.5 (GND), U6.21 (AGND), U14.5 (GND); also elsewhere on the board
MISO: J7.1, U6.16 (PB4)
MOSI: J7.2, U6.15 (PB3)
MT3608_EN: U6.9 (PD5); also elsewhere on the board
unnamed: C1.1, U6.7 (PB6/XTAL1), Y1.1
unnamed: C2.1, U6.8 (PB7/XTAL2), Y1.2
unnamed: R1.2, SW1.2, U6.29 (PC6/~RESET)
unnamed: U6.11 (PD7), U14.2 (~RE), U14.3 (DE)
unnamed: U6.31 (PD1), U14.4 (DI)
unnamed: U6.30 (PD0), U14.1 (RO)
RELAY_OUT: U6.26 (PC3); also elsewhere on the board
RESETSPI: J7.3, U6.19 (ADC6)
RS458R+: R26.1, R27.2, U14.6 (A); also elsewhere on the board
RS458R-: R26.2, R28.1, U14.7 (B); also elsewhere on the board
SCK: J7.4, U6.17 (PB5)
SCL: J7.5, U6.27 (PC4)
SDA: J7.6, U6.28 (PC5)

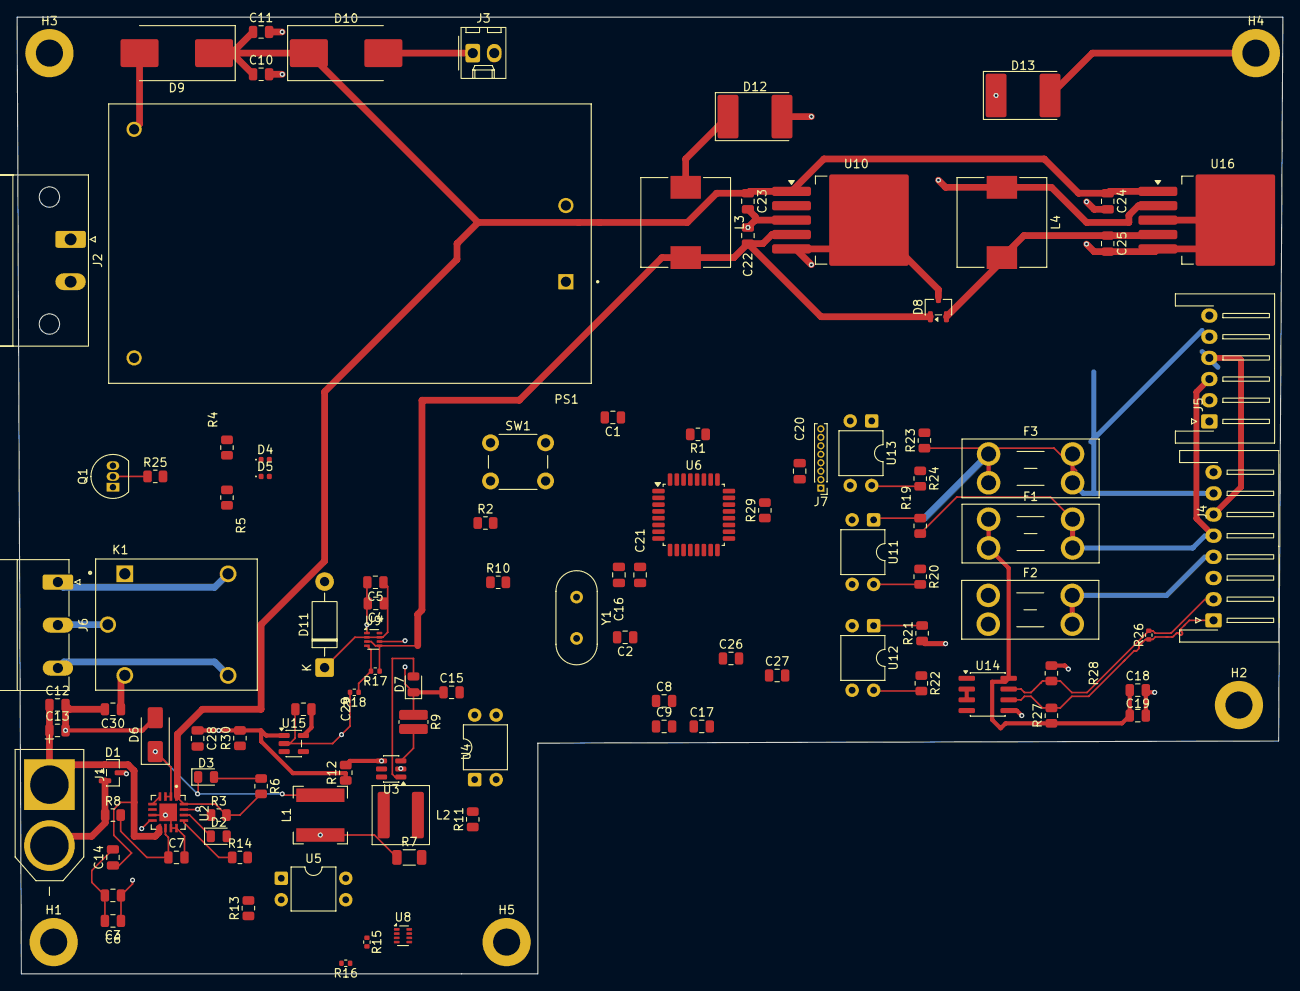
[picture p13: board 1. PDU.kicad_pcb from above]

Board: 4 copper layers, 149.5 x 113.0 mm, 111 parts (0 on the bottom side), 74 nets.

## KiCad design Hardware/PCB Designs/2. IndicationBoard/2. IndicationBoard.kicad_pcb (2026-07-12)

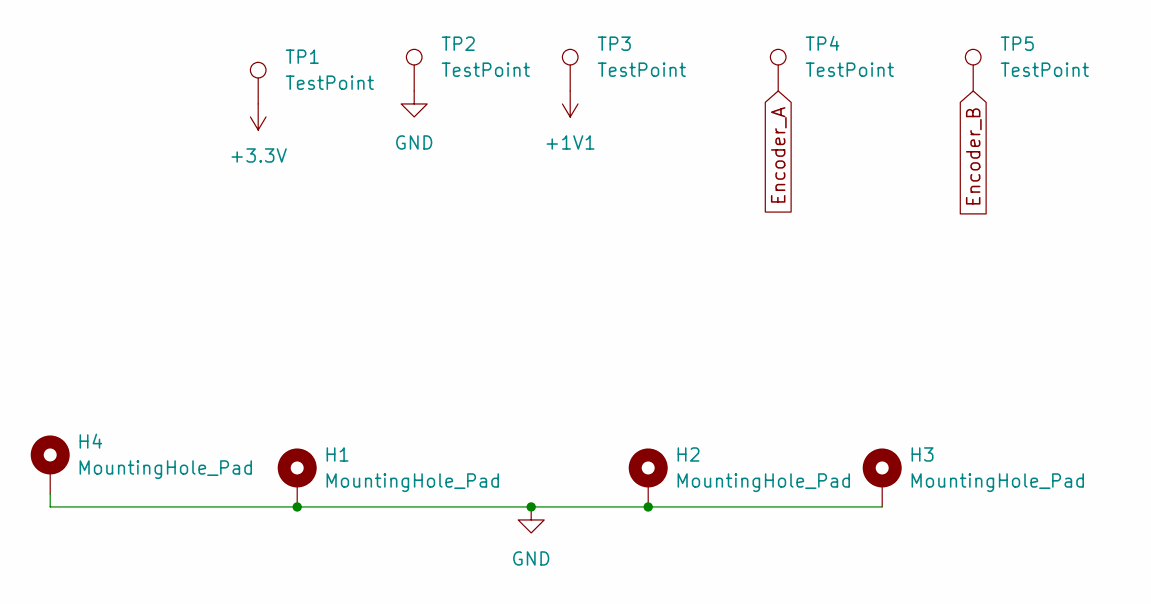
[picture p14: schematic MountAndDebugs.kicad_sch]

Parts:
H1, H2, H3, H4: MountingHole_Pad; MountingHole_2.2mm_M2_ISO7380_Pad
TP1, TP2, TP3, TP4, TP5: TestPoint; TestPoint_Pad_2.5x2.5mm

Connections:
+1V1: TP3.1; also elsewhere on the board
+3.3V: TP1.1; also elsewhere on the board
Encoder_A: TP4.1; also elsewhere on the board
Encoder_B: TP5.1; also elsewhere on the board
GND: H1.1, H2.1, H3.1, H4.1, TP2.1; also elsewhere on the board

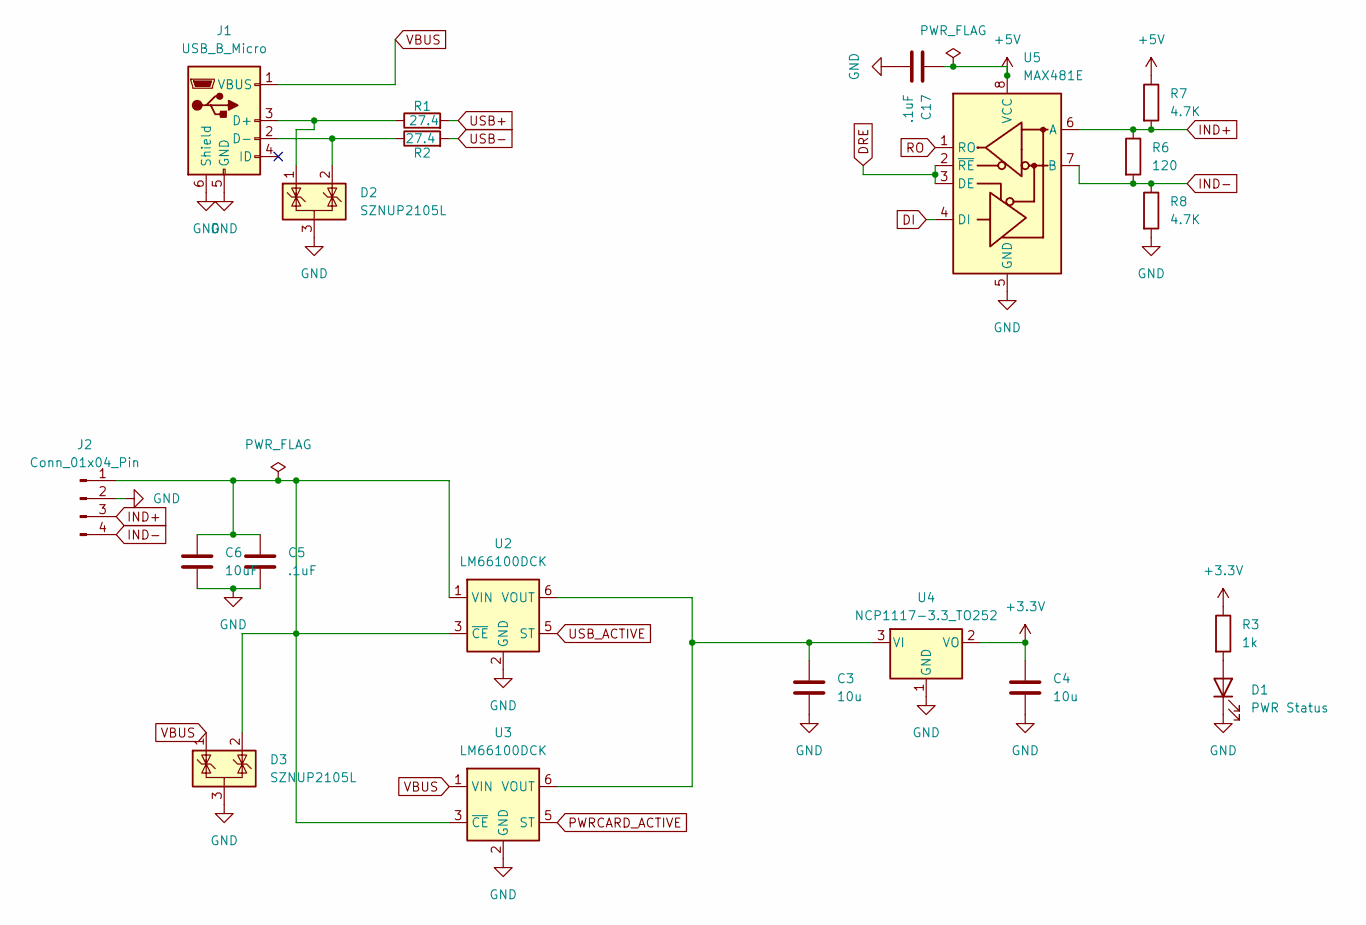
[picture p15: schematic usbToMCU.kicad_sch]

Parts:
C3, C4: 10u; C_0402_1005Metric
C5: .1uF; C_0402_1005Metric
C6: 10uF; C_0402_1005Metric
C17: .1uF; C_0805_2012Metric
D1: PWR Status; LED_0402_1005Metric_Pad0.77x0.64mm_HandSolder
D2, D3: SZNUP2105L; SOT-23
J1: USB_B_Micro; USB_Micro-B_Molex_47346-0001
J2: Conn_01x04_Pin; JST_PH_S4B-PH-K_1x04_P2.00mm_Horizontal
R1, R2: 27.4; R_0402_1005Metric
R3: 1k; R_0402_1005Metric
R6: 120; R_0402_1005Metric
R7, R8: 4.7K; R_0805_2012Metric
U2, U3: LM66100DCK; SOT-363_SC-70-6
U4: NCP1117-3.3_TO252; TO-252-2
U5: MAX481E; SOIC-8_3.9x4.9mm_P1.27mm

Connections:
+3.3V: C4.1, R3.1, U4.2 (VO); also elsewhere on the board
+5V: C17.1, R7.1, U5.8 (VCC)
DI: U5.4 (DI); also elsewhere on the board
DRE: U5.2 (~RE), U5.3 (DE); also elsewhere on the board
GND: C3.2, C4.2, C5.2, C6.2, C17.2, D1.1 (K), D2.3 (A), D3.3 (A), J1.5 (GND), J1.6 (Shield), J2.2, R8.2, U2.2 (GND), U3.2 (GND), U4.1 (GND), U5.5 (GND); also elsewhere on the board
IND+: J2.3, R6.1, R7.2, U5.6 (A)
IND-: J2.4, R6.2, R8.1, U5.7 (B)
unnamed: D1.2 (A), R3.2
unnamed: D2.1 (K), J1.3 (D+), R1.1
unnamed: D2.2 (K), J1.2 (D-), R2.1
unnamed: C5.1, C6.1, D3.2 (K), J2.1, U2.1 (VIN), U2.3 (~CE), U3.3 (~CE)
unnamed: C3.1, U2.6 (VOUT), U3.6 (VOUT), U4.3 (VI)
PWRCARD_ACTIVE: U3.5 (ST); also elsewhere on the board
RO: U5.1 (RO); also elsewhere on the board
USB+: R1.2; also elsewhere on the board
USB-: R2.2; also elsewhere on the board
USB_ACTIVE: U2.5 (ST); also elsewhere on the board
VBUS: D3.1 (K), J1.1 (VBUS), U3.1 (VIN)

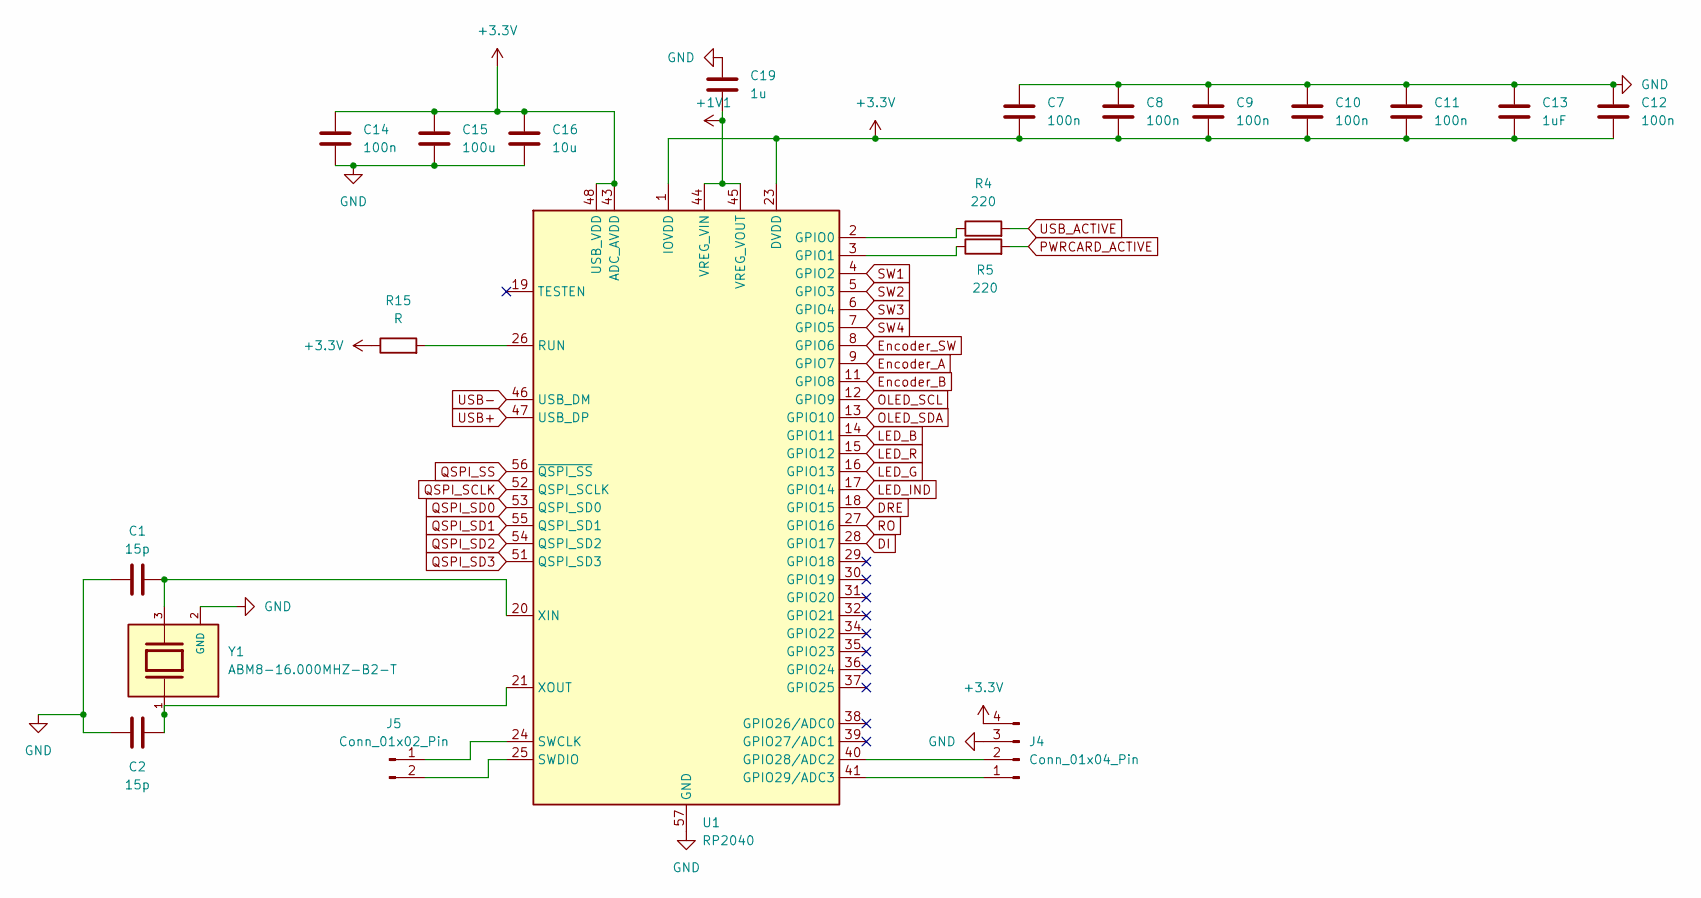
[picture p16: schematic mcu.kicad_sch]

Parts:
C1, C2: 15p; C_0402_1005Metric
C7, C8, C9, C10, C11, C12, C14: 100n; C_0201_0603Metric
C13: 1uF; C_0201_0603Metric
C15: 100u; C_0201_0603Metric
C16: 10u; C_0201_0603Metric
C19: 1u; C_0201_0603Metric
J4: Conn_01x04_Pin; PinSocket_1x04_P1.00mm_Vertical
J5: Conn_01x02_Pin; PinSocket_1x02_P2.00mm_Vertical
R4, R5: 220; R_0402_1005Metric
R15: R; R_0201_0603Metric
U1: RP2040; QFN-56-1EP_7x7mm_P0.4mm_EP3.2x3.2mm
Y1: ABM8-16.000MHZ-B2-T; XTAL_ABM8-16.000MHZ-B2-T; PARTREV 44041

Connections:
+1V1: C19.2, U1.44 (VREG_VIN), U1.45 (VREG_VOUT); also elsewhere on the board
+3.3V: C7.2, C8.2, C9.2, C10.2, C11.2, C12.2, C13.2, C14.1, C15.1, C16.1, J4.4, R15.1, U1.1 (IOVDD), U1.10 (IOVDD), U1.22 (IOVDD), U1.23 (DVDD), U1.33 (IOVDD), U1.42 (IOVDD), U1.43 (ADC_AVDD), U1.48 (USB_VDD), U1.49 (IOVDD), U1.50 (DVDD); also elsewhere on the board
DI: U1.28 (GPIO17); also elsewhere on the board
DRE: U1.18 (GPIO15); also elsewhere on the board
Encoder_A: U1.9 (GPIO7); also elsewhere on the board
Encoder_B: U1.11 (GPIO8); also elsewhere on the board
Encoder_SW: U1.8 (GPIO6); also elsewhere on the board
GND: C1.1, C2.1, C7.1, C8.1, C9.1, C10.1, C11.1, C12.1, C13.1, C14.2, C15.2, C16.2, C19.1, J4.3, U1.57 (GND), Y1.2 (GND), Y1.4 (GND); also elsewhere on the board
LED_B: U1.14 (GPIO11); also elsewhere on the board
LED_G: U1.16 (GPIO13); also elsewhere on the board
LED_IND: U1.17 (GPIO14); also elsewhere on the board
LED_R: U1.15 (GPIO12); also elsewhere on the board
unnamed: J4.1, U1.41 (GPIO29/ADC3)
unnamed: J4.2, U1.40 (GPIO28/ADC2)
unnamed: J5.1, U1.24 (SWCLK)
unnamed: J5.2, U1.25 (SWDIO)
unnamed: R4.1, U1.2 (GPIO0)
unnamed: R5.1, U1.3 (GPIO1)
unnamed: R15.2, U1.26 (RUN)
unnamed: C1.2, U1.20 (XIN), Y1.3
unnamed: C2.2, U1.21 (XOUT), Y1.1
OLED_SCL: U1.12 (GPIO9); also elsewhere on the board
OLED_SDA: U1.13 (GPIO10); also elsewhere on the board
PWRCARD_ACTIVE: R5.2; also elsewhere on the board
QSPI_SCLK: U1.52 (QSPI_SCLK); also elsewhere on the board
QSPI_SD0: U1.53 (QSPI_SD0); also elsewhere on the board
QSPI_SD1: U1.55 (QSPI_SD1); also elsewhere on the board
QSPI_SD2: U1.54 (QSPI_SD2); also elsewhere on the board
QSPI_SD3: U1.51 (QSPI_SD3); also elsewhere on the board
QSPI_SS: U1.56 (~QSPI_SS); also elsewhere on the board
RO: U1.27 (GPIO16); also elsewhere on the board
SW1: U1.4 (GPIO2); also elsewhere on the board
SW2: U1.5 (GPIO3); also elsewhere on the board
SW3: U1.6 (GPIO4); also elsewhere on the board
SW4: U1.7 (GPIO5); also elsewhere on the board
USB+: U1.47 (USB_DP); also elsewhere on the board
USB-: U1.46 (USB_DM); also elsewhere on the board
USB_ACTIVE: R4.2; also elsewhere on the board

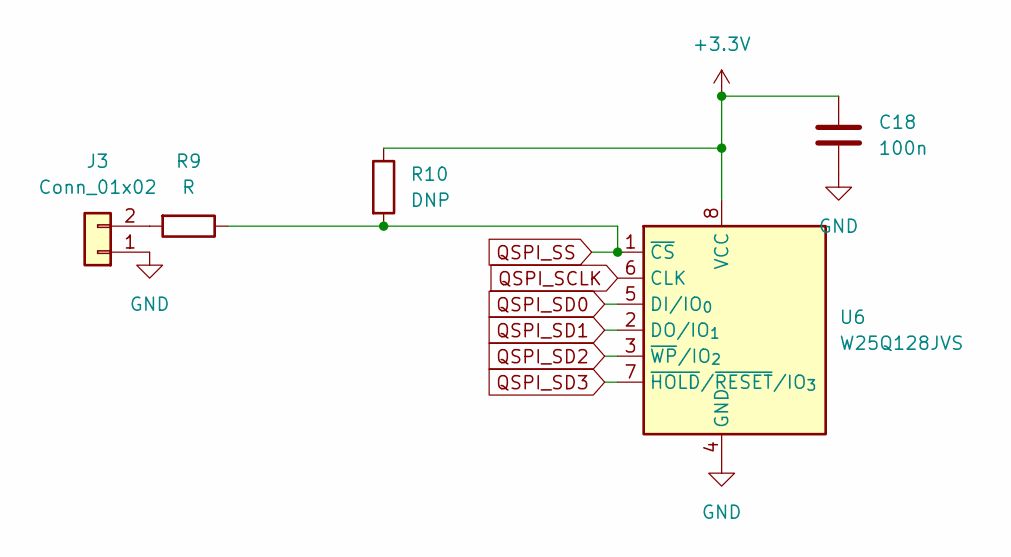
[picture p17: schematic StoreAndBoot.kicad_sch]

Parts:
C18: 100n; C_0402_1005Metric
J3: Conn_01x02; PinHeader_1x02_P1.00mm_Vertical
R9: R; R_0402_1005Metric
R10: DNP; R_0805_2012Metric
U6: W25Q128JVS; SOIC-8_5.3x5.3mm_P1.27mm

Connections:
+3.3V: C18.1, R10.1, U6.8 (VCC); also elsewhere on the board
GND: C18.2, J3.1, U6.4 (GND); also elsewhere on the board
unnamed: J3.2, R9.2
QSPI_SCLK: U6.6 (CLK); also elsewhere on the board
QSPI_SD0: U6.5 (DI/IO_{0}); also elsewhere on the board
QSPI_SD1: U6.2 (DO/IO_{1}); also elsewhere on the board
QSPI_SD2: U6.3 (~WP/IO_{2}); also elsewhere on the board
QSPI_SD3: U6.7 (~HOLD/~RESET/IO_{3}); also elsewhere on the board
QSPI_SS: R9.1, R10.2, U6.1 (~CS); also elsewhere on the board

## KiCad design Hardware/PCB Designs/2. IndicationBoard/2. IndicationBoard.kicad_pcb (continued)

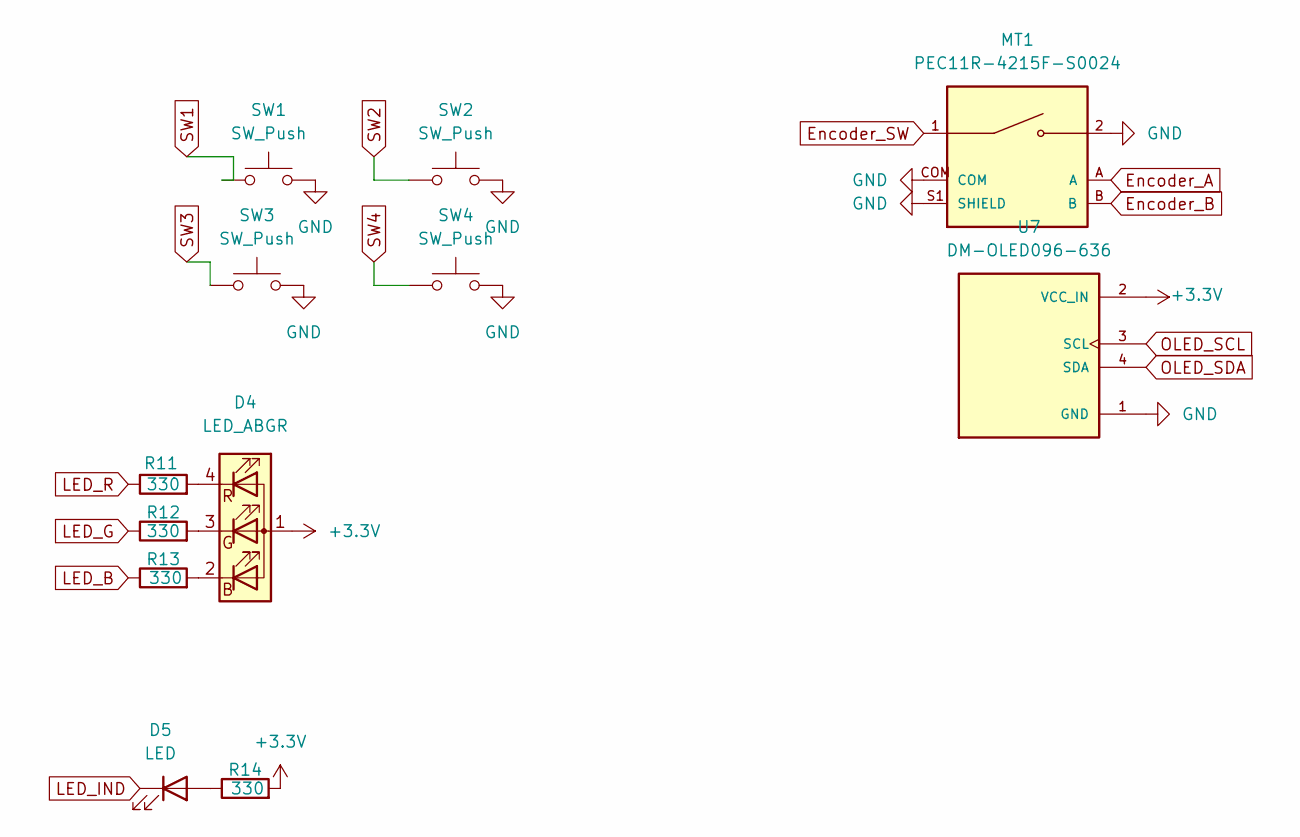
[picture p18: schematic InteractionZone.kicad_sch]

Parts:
D4: LED_ABGR; LED_RGB_Wuerth-PLCC4_3.2x2.8mm_150141M173100
D5: LED; LED_0805_2012Metric
MT1: PEC11R-4215F-S0024; XDCR_PEC11R-4215F-S0024; PARTREV Rev. 09/19
R11, R12, R13, R14: 330; R_0201_0603Metric
SW1, SW2, SW3, SW4: SW_Push; SW_PUSH_6mm_H8mm
U7: DM-OLED096-636; MODULE_DM-OLED096-636; PARTREV 2018-09-10

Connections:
+3.3V: D4.1 (A), R14.2, U7.2 (VCC_IN); also elsewhere on the board
Encoder_A: MT1.A; also elsewhere on the board
Encoder_B: MT1.B; also elsewhere on the board
Encoder_SW: MT1.1; also elsewhere on the board
GND: MT1.2, MT1.COM, MT1.S1 (SHIELD), MT1.S2 (SHIELD), SW1.2, SW2.2, SW3.2, SW4.2, U7.1 (GND); also elsewhere on the board
LED_B: R13.1; also elsewhere on the board
LED_G: R12.1; also elsewhere on the board
LED_IND: D5.1 (K); also elsewhere on the board
LED_R: R11.1; also elsewhere on the board
unnamed: D4.2 (BK), R13.2
unnamed: D4.3 (GK), R12.2
unnamed: D4.4 (RK), R11.2
unnamed: D5.2 (A), R14.1
OLED_SCL: U7.3 (SCL); also elsewhere on the board
OLED_SDA: U7.4 (SDA); also elsewhere on the board
SW1: SW1.1; also elsewhere on the board
SW2: SW2.1; also elsewhere on the board
SW3: SW3.1; also elsewhere on the board
SW4: SW4.1; also elsewhere on the board

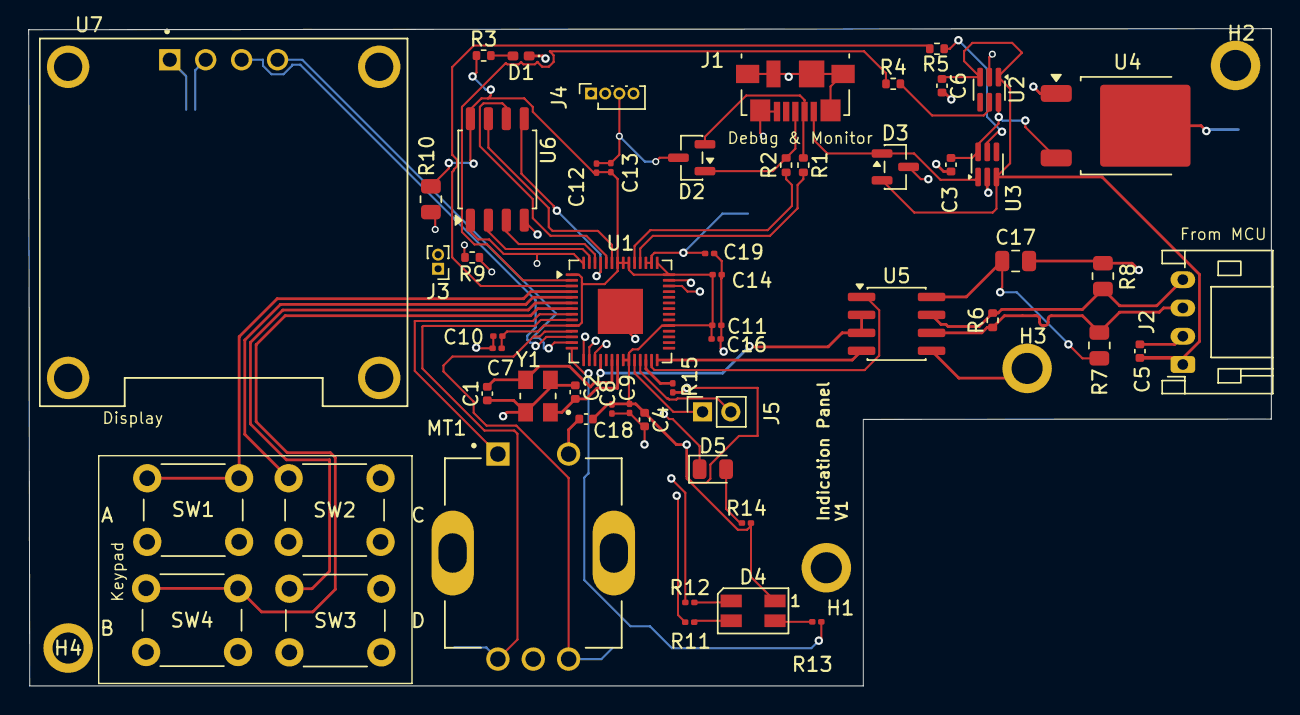
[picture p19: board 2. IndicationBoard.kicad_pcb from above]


Board: 4 copper layers, 87.9 x 46.5 mm, 66 parts (6 on the bottom side), 52 nets.

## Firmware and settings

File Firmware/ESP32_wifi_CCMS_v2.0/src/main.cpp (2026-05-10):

#include <Arduino.h>
#include <WiFi.h>
#include <WiFiClientSecure.h>
#include <Wire.h>
#include <RTClib.h>
#include <DHT.h>
#include <Adafruit_GFX.h>
#include <Adafruit_SSD1306.h>
#include <ArduinoJson.h>
#include <time.h>
#include "config.h"
#include "wifi_handler.h"
#include "mqtt_handler.h"
#include "meter_handler.h"

WiFiClientSecure espClient;
RTC_DS3231 rtc;
DHT dht(DHT_PIN, DHT_TYPE);
Adafruit_SSD1306 display(SCREEN_WIDTH, SCREEN_HEIGHT, &Wire, OLED_RESET);

float batteryVoltage = 0.0f;
float mainsRaw = 0.0f;
int tiltSwitchState = 0;
float currentTemp = 0.0f;

// UI & Button State
int currentScreen = 0;
const int NUM_SCREENS = 3;
bool lastButtonState = HIGH;
unsigned long lastDebounceTime = 0;
const unsigned long debounceDelay = 50;
unsigned long lastScreenSwitchTime = 0;
const unsigned long screenSwitchInterval = 5000; // 5 seconds auto-switch

void displayStatusMessage(String msg)
{
  display.clearDisplay();
  display.setTextSize(1);
  display.setTextColor(SSD1306_WHITE);
  display.setCursor(0, 0);
  display.println(F("--- BOOT SEQUENCE ---"));
  display.println(msg);
  display.display();
}

void syncNTP()
{
  Serial.print("Syncing time with NTP...");
  displayStatusMessage("Syncing NTP...");
  configTime(19800, 0, "pool.ntp.org", "time.nist.gov"); // IST (5.5 hrs * 3600)
  time_t now = time(nullptr);
  int retry = 0;
  while (now < 100000 && retry < 10)
  {
    delay(1000);
    Serial.print(".");
    now = time(nullptr);
    retry++;
  }
  if (now >= 100000)
  {
    rtc.adjust(DateTime(now));
    Serial.println(" RTC updated from NTP.");
    displayStatusMessage("NTP Sync Success");
  }
  else
  {
    Serial.println(" NTP Sync Failed.");
    displayStatusMessage("NTP Sync Failed");
  }
  delay(1000);
}

void mqttCallback(char *topic, byte *payload, unsigned int length)
{
  // Handle both delta and update topics
  bool isDelta = strcmp(topic, SHADOW_DELTA_TOPIC) == 0;
  bool isUpdate = strcmp(topic, SHADOW_UPDATE_TOPIC) == 0;
  
  if (isDelta || isUpdate)
  {
    if (isDelta) {
      Serial.println("TACTICAL ALERT: Multi-Vector Shadow Delta Received.");
    } else {
      Serial.println("TACTICAL ALERT: Shadow Update Received.");
    }

    JsonDocument doc;
    DeserializationError error = deserializeJson(doc, payload, length);
    if (error)
    {
      Serial.println("JSON Parse Failed.");
      return;
    }

    JsonObject state = doc["state"].as<JsonObject>();
    
    // Get desired state (for update topic) or direct state (for delta topic)
    JsonObject desiredState = state["desired"].is<JsonObject>() ? state["desired"].as<JsonObject>() : state;
    
    // For delta messages, state might be directly under "state" object
    if (isDelta && desiredState.size() == 0) {
      desiredState = state;
    }
    
    bool stateChanged = false;

    // PARSE RELAY COMMAND - Handle both camelCase and snake_case, and string "ON"/"OFF" values
    if (desiredState["relayState"].is<bool>())
    {
      currentRelayState = desiredState["relayState"];
      digitalWrite(RELAY_PIN, currentRelayState ? HIGH : LOW);
      Serial.print("Relay GPIO switched to: ");
      Serial.println(currentRelayState ? "ON" : "OFF");
      stateChanged = true;
    }
    else if (desiredState["relay_state"].is<bool>())
    {
      currentRelayState = desiredState["relay_state"];
      digitalWrite(RELAY_PIN, currentRelayState ? HIGH : LOW);
      Serial.print("Relay GPIO switched to: ");
      Serial.println(currentRelayState ? "ON" : "OFF");
      stateChanged = true;
    }
    else if (desiredState["relay_state"].is<String>())
    {
      String relayStateStr = desiredState["relay_state"].as<String>();
      relayStateStr.toUpperCase();
      if (relayStateStr == "ON")
      {
        currentRelayState = true;
        digitalWrite(RELAY_PIN, HIGH);
        Serial.println("Relay GPIO switched to: ON");
        stateChanged = true;
      }
      else if (relayStateStr == "OFF")
      {
        currentRelayState = false;
        digitalWrite(RELAY_PIN, LOW);
        Serial.println("Relay GPIO switched to: OFF");
        stateChanged = true;
      }
    }

    // PARSE TIMING/SCHEDULE COMMANDS - Handle both camelCase and snake_case
    if (desiredState["timeToAutoTurnOn"].is<String>())
    {
      autoOnTime = desiredState["timeToAutoTurnOn"].as<String>();
      Serial.println("New Auto-ON Schedule Locked: " + autoOnTime);
      stateChanged = true;
    }
    else if (desiredState["time_to_auto_turn_on"].is<String>())
    {
      autoOnTime = desiredState["time_to_auto_turn_on"].as<String>();
      Serial.println("New Auto-ON Schedule Locked: " + autoOnTime);
      stateChanged = true;
    }

    if (desiredState["timeToAutoTurnOff"].is<String>())
    {
      autoOffTime = desiredState["timeToAutoTurnOff"].as<String>();
      Serial.println("New Auto-OFF Schedule Locked: " + autoOffTime);
      stateChanged = true;
    }
    else if (desiredState["time_to_auto_turn_off"].is<String>())
    {
      autoOffTime = desiredState["time_to_auto_turn_off"].as<String>();
      Serial.println("New Auto-OFF Schedule Locked: " + autoOffTime);
      stateChanged = true;
    }

    // PARSE DEVICE STATE - Handle both camelCase and snake_case, and string "ON"/"OFF" values
    if (desiredState["deviceState"].is<String>())
    {
      currentDeviceState = desiredState["deviceState"].as<String>();
      Serial.println("Device Status Override: " + currentDeviceState);
      stateChanged = true;
    }
    else if (desiredState["device_state"].is<String>())
    {
      currentDeviceState = desiredState["device_state"].as<String>();
      Serial.println("Device Status Override: " + currentDeviceState);
      stateChanged = true;
    }
  }
}

void updateOLED()
{
  display.clearDisplay();
  display.setTextSize(1);
  display.setTextColor(SSD1306_WHITE);
  display.setCursor(0, 0);

  DateTime now = rtc.now();

  switch (currentScreen)
  {
  case 0:
    // Screen 1: System & Network
    display.println(F("--- SYSTEM ---"));
    display.printf("%02d:%02d:%02d\n", now.hour(), now.minute(), now.second());
    display.print(F("WiFi: "));
    display.println(WiFi.status() == WL_CONNECTED ? F("Connected") : F("Offline"));
    display.print(F("MQTT: "));
    display.println(mqttClient.connected() ? F("Connected") : F("Offline"));
    display.print(F("Relay: "));
    display.println(currentRelayState ? F("ON") : F("OFF"));
    break;

  case 1:
    // Screen 2: Environment Sensors
    display.println(F("--- SENSORS ---"));
    display.print(F("Temp: "));
    display.print(currentTemp);
    display.println(F(" C"));
    display.print(F("Bat Voltage: "));
    display.print(batteryVoltage);
    display.println(F(" V"));
    display.print(F("Mains Val:   "));
    display.println(mainsRaw);
    display.print(F("Tilt Switch: "));
    display.println(tiltSwitchState == LOW ? F("Tilted") : F("Safe"));
    break;

  case 2:
    // Screen 3: Modbus Summary
    display.println(F("--- MODBUS ---"));
    display.print(F("R"));
    display.print(mqttRegisters[0]);
    display.print(F(": "));
    display.println(mqttValues[0]);
    display.print(F("R"));
    display.print(mqttRegisters[1]);
    display.print(F(": "));
    display.println(mqttValues[1]);
    display.print(F("R"));
    display.print(mqttRegisters[2]);
    display.print(F(": "));
    display.println(mqttValues[2]);
    display.print(F("R"));
    display.print(mqttRegisters[3]);
    display.print(F(": "));
    display.println(mqttValues[3]);
    display.println(F("(More in MQTT JSON)"));
    break;
  }
  display.display();
}

void setup()
{
  Serial.begin(115200);
  delay(50);

  // Initialize Hardware
  Wire.begin(I2C_SDA, I2C_SCL);
  if (!rtc.begin())
  {
    Serial.println("Couldn't find RTC");
  }
  dht.begin();

  pinMode(RELAY_PIN, OUTPUT);
  digitalWrite(RELAY_PIN, currentRelayState ? HIGH : LOW);
  pinMode(TILT_SW_PIN, INPUT_PULLUP);
  // ADC mapping
  // BAT_ADC_PIN & MAINS_ADC_PIN do not explicitly need pinMode but good practice
  pinMode(BAT_ADC_PIN, INPUT);
  pinMode(MAINS_ADC_PIN, INPUT);

  // Buttons, LEDs, and Bridge UART
  pinMode(BUTTON_PIN, INPUT_PULLUP);
  pinMode(LED1_PIN, OUTPUT);
  pinMode(LED2_PIN, OUTPUT);
  pinMode(LED3_PIN, OUTPUT);
  Serial1.begin(115200, SERIAL_8N1, BRIDGE_RX, BRIDGE_TX);

  if (!display.begin(SSD1306_SWITCHCAPVCC, 0x3C))
  {
    Serial.println(F("SSD1306 allocation failed"));
  }
  else
  {
    display.clearDisplay();
    display.display();
  }

  setupMeter();

  for (int i = 0; i < numMqttRegs; ++i)
    mqttValues[i] = 0.0f;

  setupWiFi();
  syncNTP();
  setupMQTT();

  Serial.println("\n--- Multifunction Meter MQTT Publisher Started ---");
}

float calculateBatteryVoltage()
{
  // The ESP32 ADC is 12-bit (0-4095) with a reference voltage of ~3.3V
  int adcValue = analogRead(BAT_ADC_PIN);
  float pinVoltage = adcValue * (3.3 / 4095.0);
  
  // Replace the factor of 4.0 with your actual voltage divider ratio: (R1 + R2) / R2
  float dividerRatio = 4.0; 
  return pinVoltage * dividerRatio;
}

void loop()
{
  if (WiFi.status() != WL_CONNECTED)
  {
    setupWiFi();
    syncNTP();
  }

  handleMQTTConnection();
  mqttClient.loop();

  // Multi-Vector Hardware Polling
  batteryVoltage = calculateBatteryVoltage();
  mainsRaw = analogRead(MAINS_ADC_PIN);
  tiltSwitchState = digitalRead(TILT_SW_PIN);
  float newTemp = dht.readTemperature();
  if (!isnan(newTemp))
  {
    currentTemp = newTemp;
  }

  // Handle Auto Screen Switch
  if (millis() - lastScreenSwitchTime > screenSwitchInterval)
  {
    currentScreen = (currentScreen + 1) % NUM_SCREENS;
    lastScreenSwitchTime = millis();
  }

  // Handle Push Button & UI
  int reading = digitalRead(BUTTON_PIN);
  if (reading != lastButtonState)
  {
    lastDebounceTime = millis();
  }
  if ((millis() - lastDebounceTime) > debounceDelay)
  {
    if (reading == LOW && lastButtonState == HIGH)
    {
      currentScreen = (currentScreen + 1) % NUM_SCREENS;
      lastScreenSwitchTime = millis(); // Reset timer on manual override
    }
  }
  lastButtonState = reading;

  updateOLED();

  // Status LEDs logic
  digitalWrite(LED1_PIN, mainsRaw > 500 ? HIGH : LOW);                                            // Mains Power OK
  digitalWrite(LED2_PIN, (WiFi.status() == WL_CONNECTED && mqttClient.connected()) ? HIGH : LOW); // Network Activity

  readMqttRegisters();

  if (millis() - lastMqttPublish >= mqttPublishInterval)
  {
    publishMqttData();
    lastMqttPublish = millis();
  }
}

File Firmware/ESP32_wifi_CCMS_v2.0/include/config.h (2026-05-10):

#ifndef CONFIG_H
#define CONFIG_H

#include <Arduino.h>

// WiFi Credentials
extern const char *ssid;
extern const char *password;

// MQTT Configuration
extern const char *mqtt_server;
extern const int mqtt_port;
extern const char *mqtt_client_id;
extern const char *mqtt_topic;

// Pin Definitions
#define RX2_PIN 16
#define TX2_PIN 17
#define I2C_SDA 21
#define I2C_SCL 22

// New Sensors & I/O
#define RELAY_PIN 14
#define BAT_ADC_PIN 34
#define MAINS_ADC_PIN 35
#define TILT_SW_PIN 15
#define DHT_PIN 4
#define DHT_TYPE 11 // DHT11

// OLED, Button, LEDs & Bridge UART
#define BUTTON_PIN 32
#define LED1_PIN 25
#define LED2_PIN 26
#define LED3_PIN 27
#define BRIDGE_TX 13
#define BRIDGE_RX 12

#define SCREEN_WIDTH 128
#define SCREEN_HEIGHT 64
#define OLED_RESET -1

// AWS Shadow Topics
extern const char *SHADOW_DELTA_TOPIC;
extern const char *SHADOW_UPDATE_TOPIC;

// GLOBAL STATE VECTORS
extern bool currentRelayState;
extern String currentDeviceState;
extern String autoOnTime;
extern String autoOffTime;
extern int currentFaultCode;

// NEW SENSOR STATES
extern float batteryVoltage;
extern float mainsRaw;
extern int tiltSwitchState;
extern float currentTemp;

// Modbus & MQTT Configuration
extern bool useByteSwap;

extern uint16_t mqttRegisters[];
extern const int numMqttRegs;
extern float mqttValues[];

extern unsigned long lastMqttPublish;
extern const unsigned long mqttPublishInterval;

// Display helper
void displayStatusMessage(String msg);

#endif

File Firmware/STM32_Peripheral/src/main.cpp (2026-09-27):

#include <Arduino.h>
#include "serial_handler.h"
#include "meter_handler.h"

// Define Pins
#define RELAY_PIN PA0
#define BAT_ADC_PIN PA1
#define MAINS_ADC_PIN PA2
#define TILT_SW_PIN PA3

unsigned long lastTelemetryTime = 0;
const unsigned long TELEMETRY_INTERVAL = 5000; // 5 seconds

void setup() {
    // Initialize UART communication with Raspberry Pi
    SerialHandler::init(115200);
    
    // Initialize Hardware Pins
    pinMode(RELAY_PIN, OUTPUT);
    digitalWrite(RELAY_PIN, LOW);
    
    pinMode(BAT_ADC_PIN, INPUT_ANALOG);
    pinMode(MAINS_ADC_PIN, INPUT_ANALOG);
    pinMode(TILT_SW_PIN, INPUT_PULLUP);
    
    // Initialize Modbus Meter
    MeterHandler::init();
}

void loop() {
    // Process incoming commands from Pi
    SerialHandler::processIncoming(RELAY_PIN);
    
    // Periodically send telemetry to Pi
    if (millis() - lastTelemetryTime > TELEMETRY_INTERVAL) {
        lastTelemetryTime = millis();
        
        // Read Sensors
        float batteryVoltage = analogRead(BAT_ADC_PIN) * (3.3 / 4095.0) * 4.0;
        int mainsRaw = analogRead(MAINS_ADC_PIN);
        int tiltState = digitalRead(TILT_SW_PIN);
        
        // Read Modbus Registers
        MeterData meterData = MeterHandler::readRegisters();
        
        // Send JSON Telemetry
        SerialHandler::sendTelemetry(batteryVoltage, mainsRaw, tiltState, meterData);
    }
}

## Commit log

2026-07-12 Refactor folder structure and update README
    [1. PDU.kicad_pcb, 1. PDU.kicad_sch, 2. IndicationBoard.kicad_pcb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]
2026-07-12 Update docs/index.md with new assets
    [1. PDU.kicad_pcb, 1. PDU.kicad_sch, Filter and Oring_sch.kicad_sch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]
2026-09-27 Introduce RPi Gateway and STM32 Peripheral edge architecture
2026-10-14 Add ESP32 firmware v3.0: relay on GPIO23, no external RTC (NTP-based internal clock)
